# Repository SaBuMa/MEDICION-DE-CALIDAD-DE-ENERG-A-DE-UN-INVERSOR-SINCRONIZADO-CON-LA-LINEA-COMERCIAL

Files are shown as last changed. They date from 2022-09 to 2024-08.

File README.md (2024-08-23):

# Medición de calidad de energía de un inversor sincronizado con la línea comercial
Para este proyecto se realiza el diseño e implementación de un  inversor sincronizado con la línea comercial.

__Aplicaciones:__  
* Fuente de poder ininterrumpida.  
* Red de energía.  
* Paneles solares.

## Como características funcionales de este proyecto se tienen:

* __Inversor__
    * Vo = 9 VRMS  ± 2%
    * Fo = 60 Hz ± 5%
    * Po = 15W
* __Sincronización__
    * Enganche Fo = 60 Hz ± 5% (57 Hz – 63 Hz)
* __Medición de calidad__
    * Medición con módulo de adquisición
    * Acondicionamiento  de entrada de voltaje y corriente.
    * Rango dinámico de 80 dB
    * Variables a medir Vo (RMS), Io (RMS) y THD para estas.

## Equipo electrónico utilizado en este proyecto

<p align="center">
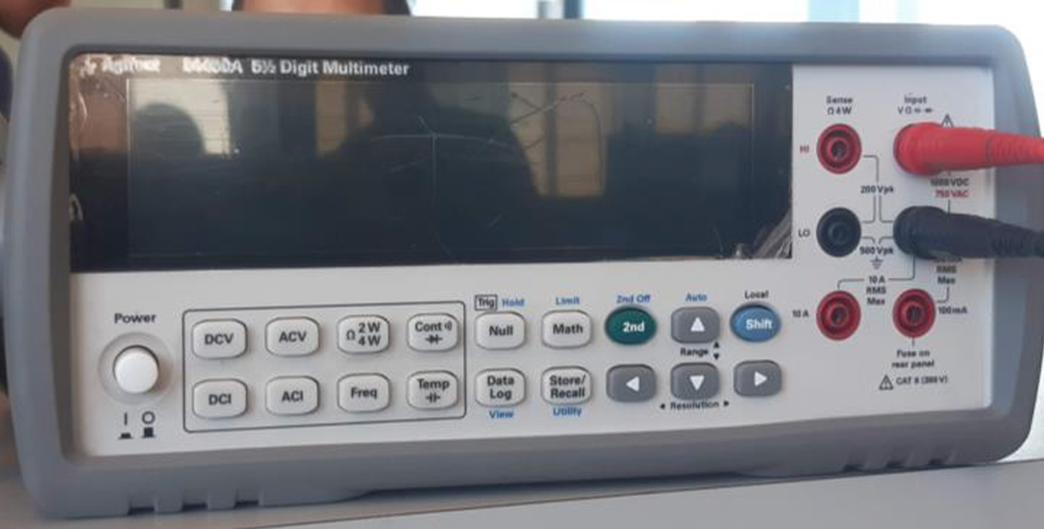
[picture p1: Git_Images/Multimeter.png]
Multimeter
  
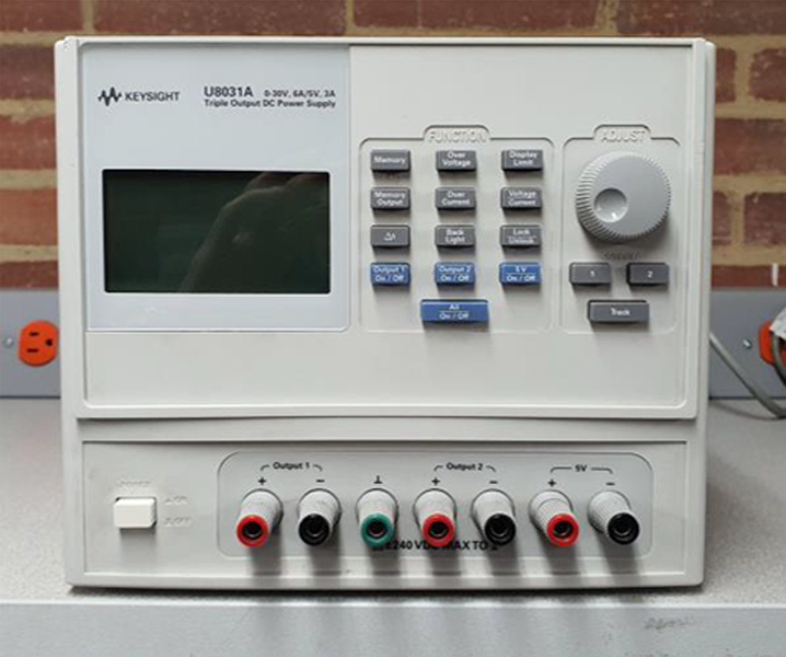
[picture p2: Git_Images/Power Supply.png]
Power Supply

</p>

<p align="center">
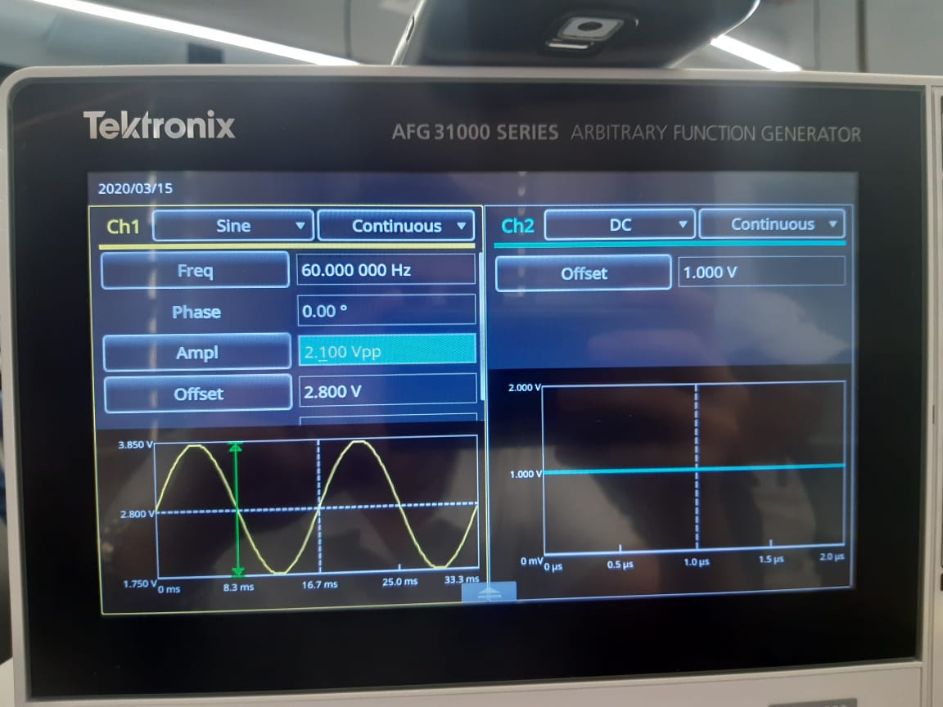
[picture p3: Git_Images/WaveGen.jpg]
WaveGen

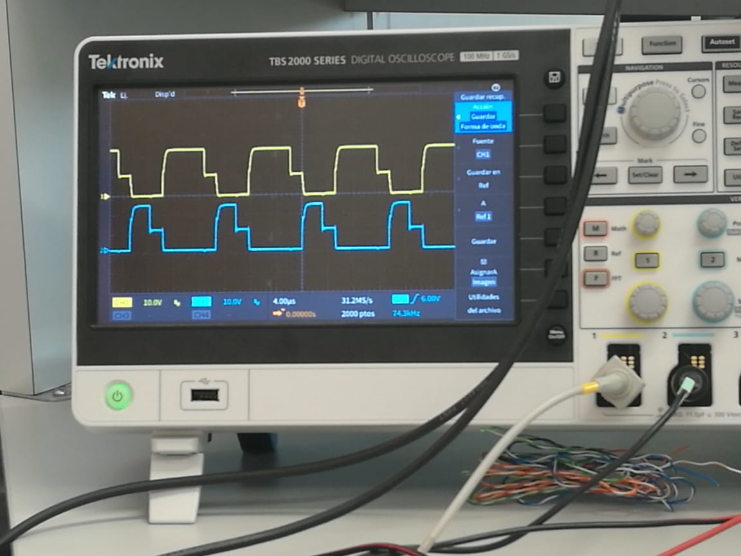
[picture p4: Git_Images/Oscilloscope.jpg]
Oscilloscope

</p>

## Diagrama Bloques proyecto
<p align="center">
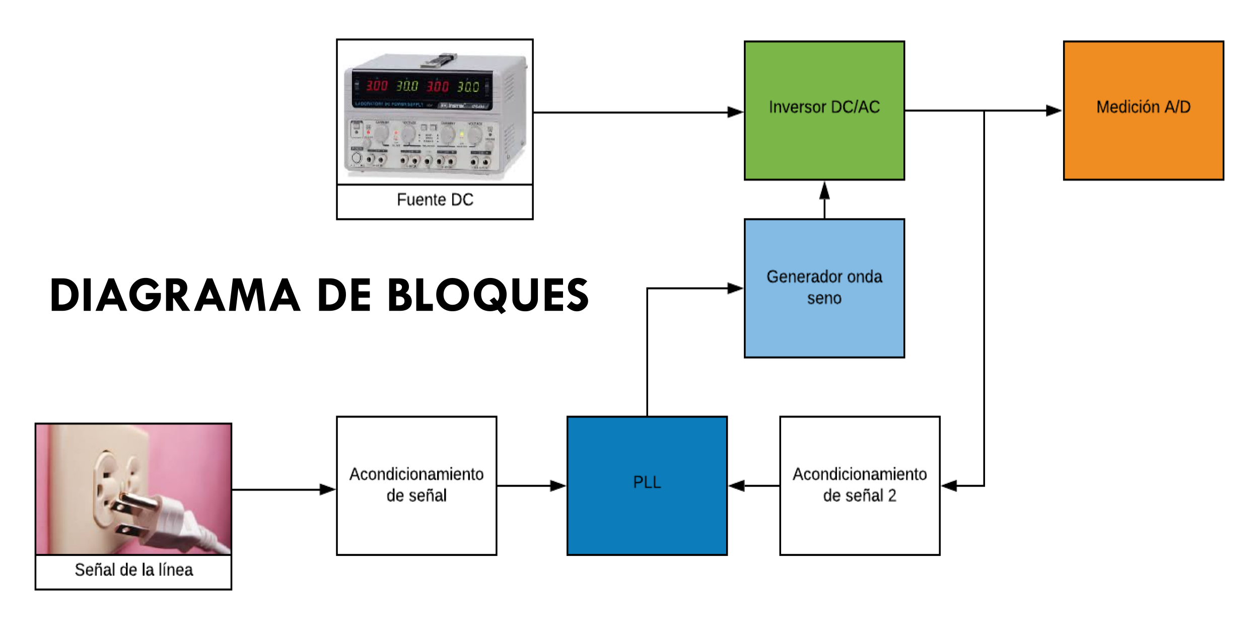
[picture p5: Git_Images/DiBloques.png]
DiBloques
  
</p>

## Acondicionamiento línea comercial  
Reducir el voltaje de 120 VRMS AC de la línea a un voltaje no mayor a 9 VRMS AC.
Proporcionar la señal cuadrada al PLL para que este funcione correctamente.

## Circuito Inversor Esquemático  
<p align="center">
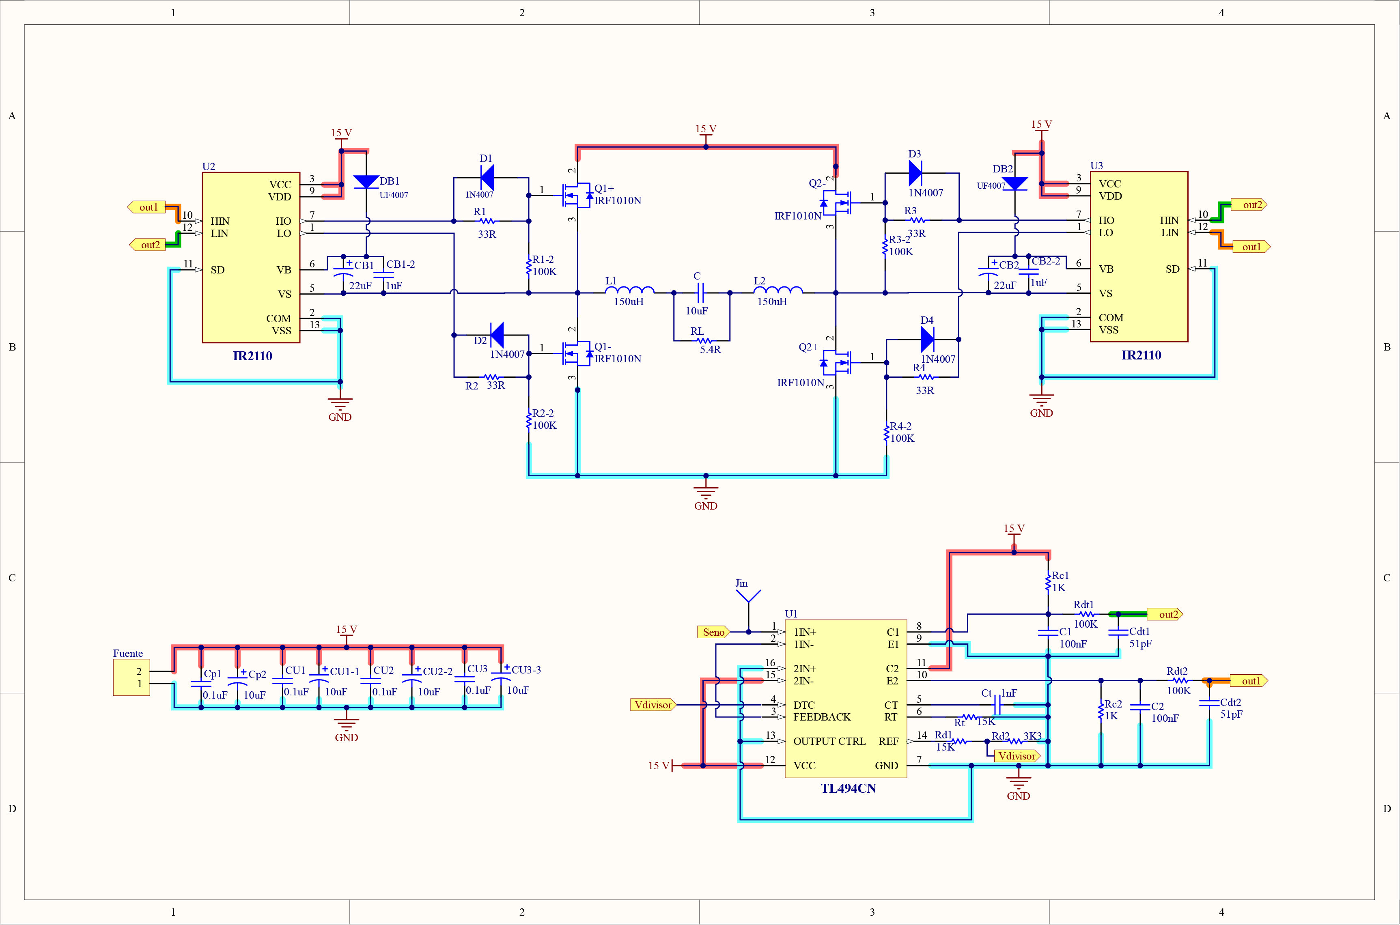
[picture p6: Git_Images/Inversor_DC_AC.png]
Inversor_DC_AC
  
</p>

## Circuito PLL  
Debe sincronizar la salida del inversor con la línea comercial acondicionada.  
Capacidad de enganchar una señal a la línea en un rango de +- 3 Hz.

<p align="center">
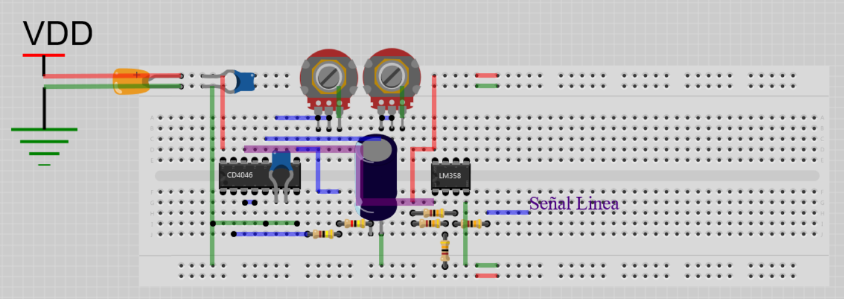
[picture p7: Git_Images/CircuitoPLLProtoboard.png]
CircuitoPLLProtoboard
  
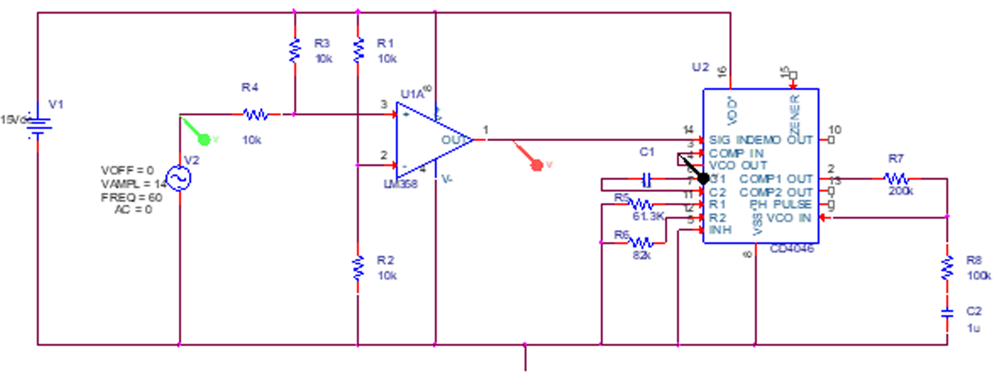
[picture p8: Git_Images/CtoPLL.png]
CtoPLL
  
</p>

## Circuito VCO - Generador onda seno  
<p align="center">
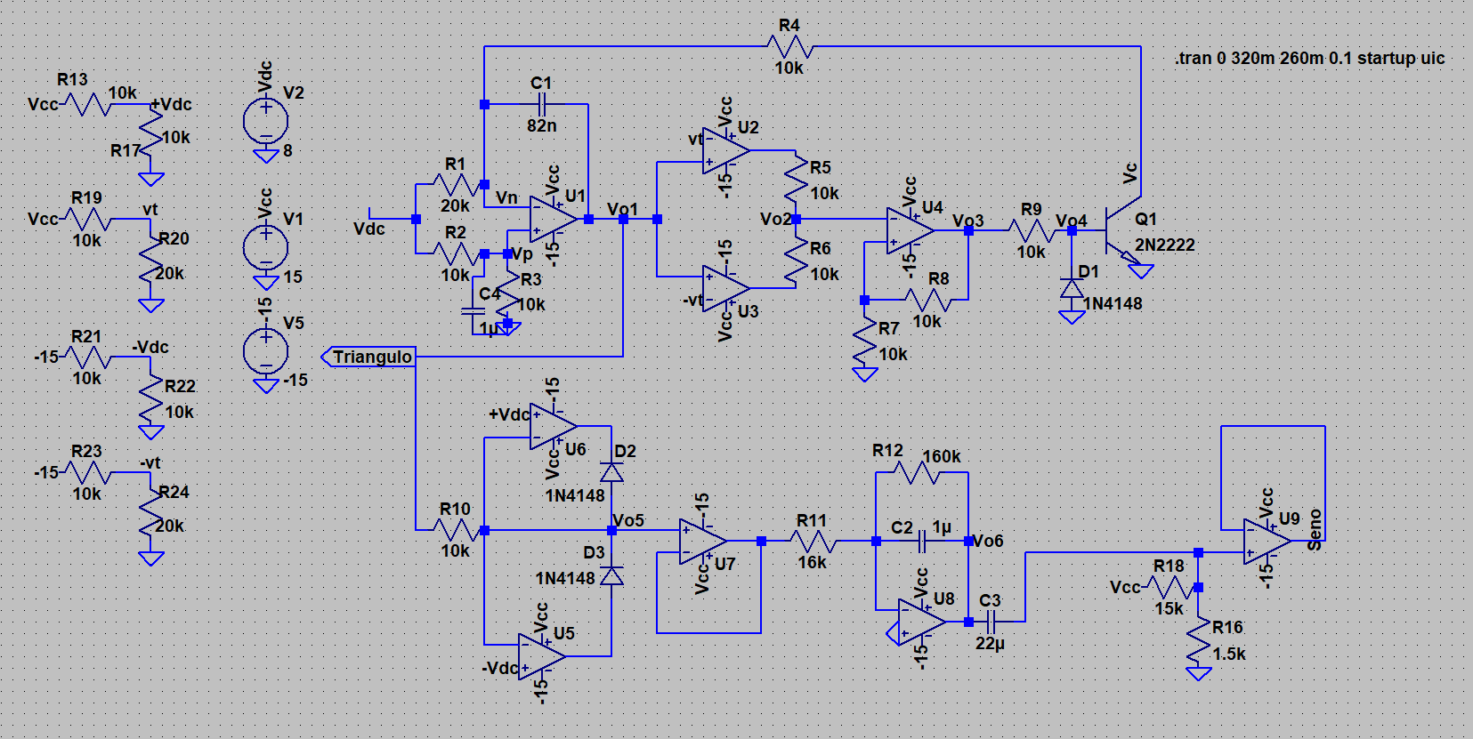
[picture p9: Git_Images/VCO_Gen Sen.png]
VCO_Gen Sen
  
</p>

## PCB del Proyecto  

<p align="center">
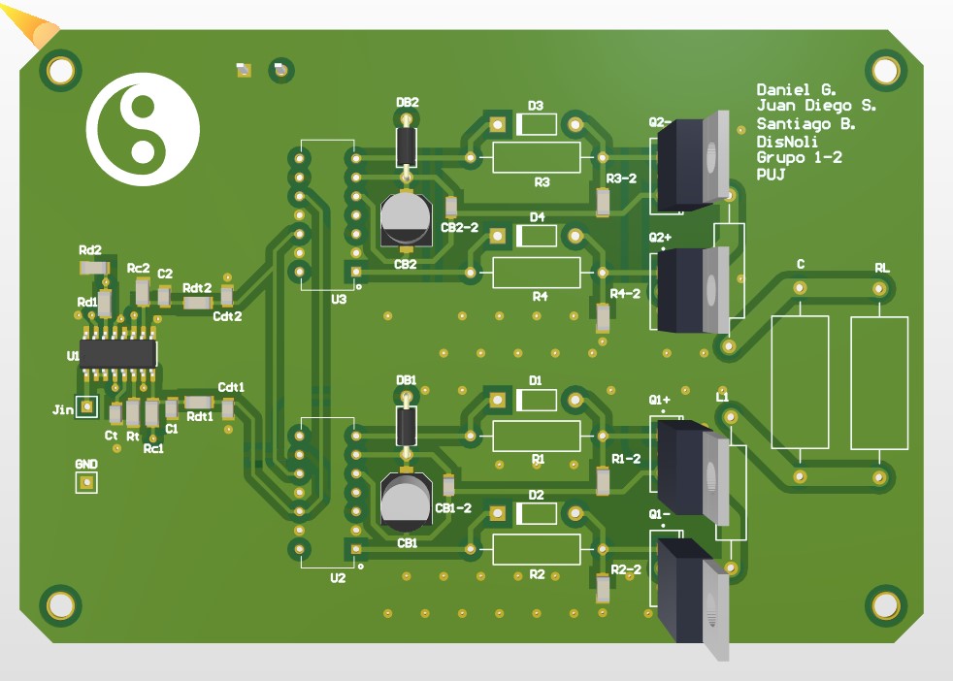
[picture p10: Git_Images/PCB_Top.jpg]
PCB_Top
  
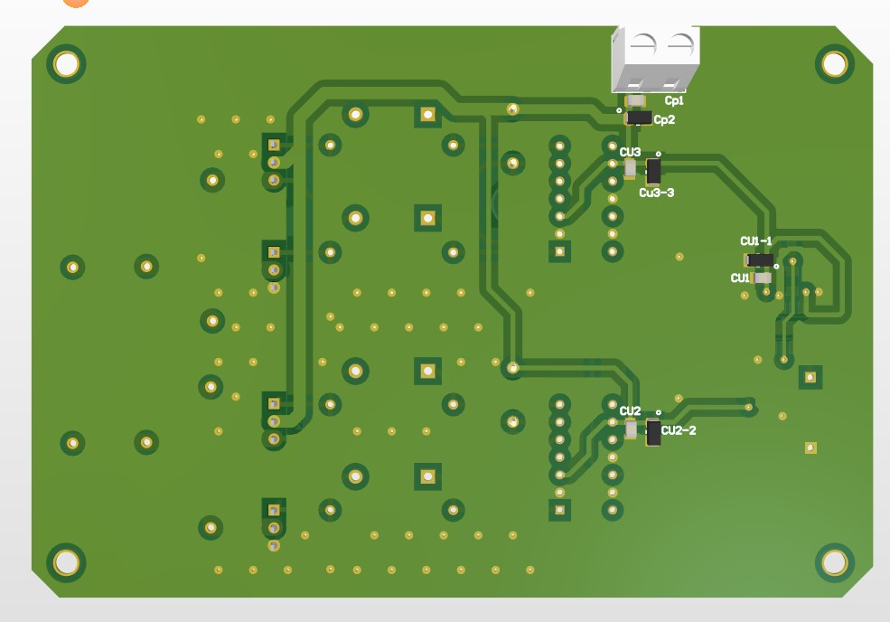
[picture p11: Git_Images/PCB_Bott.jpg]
PCB_Bott
  
</p>

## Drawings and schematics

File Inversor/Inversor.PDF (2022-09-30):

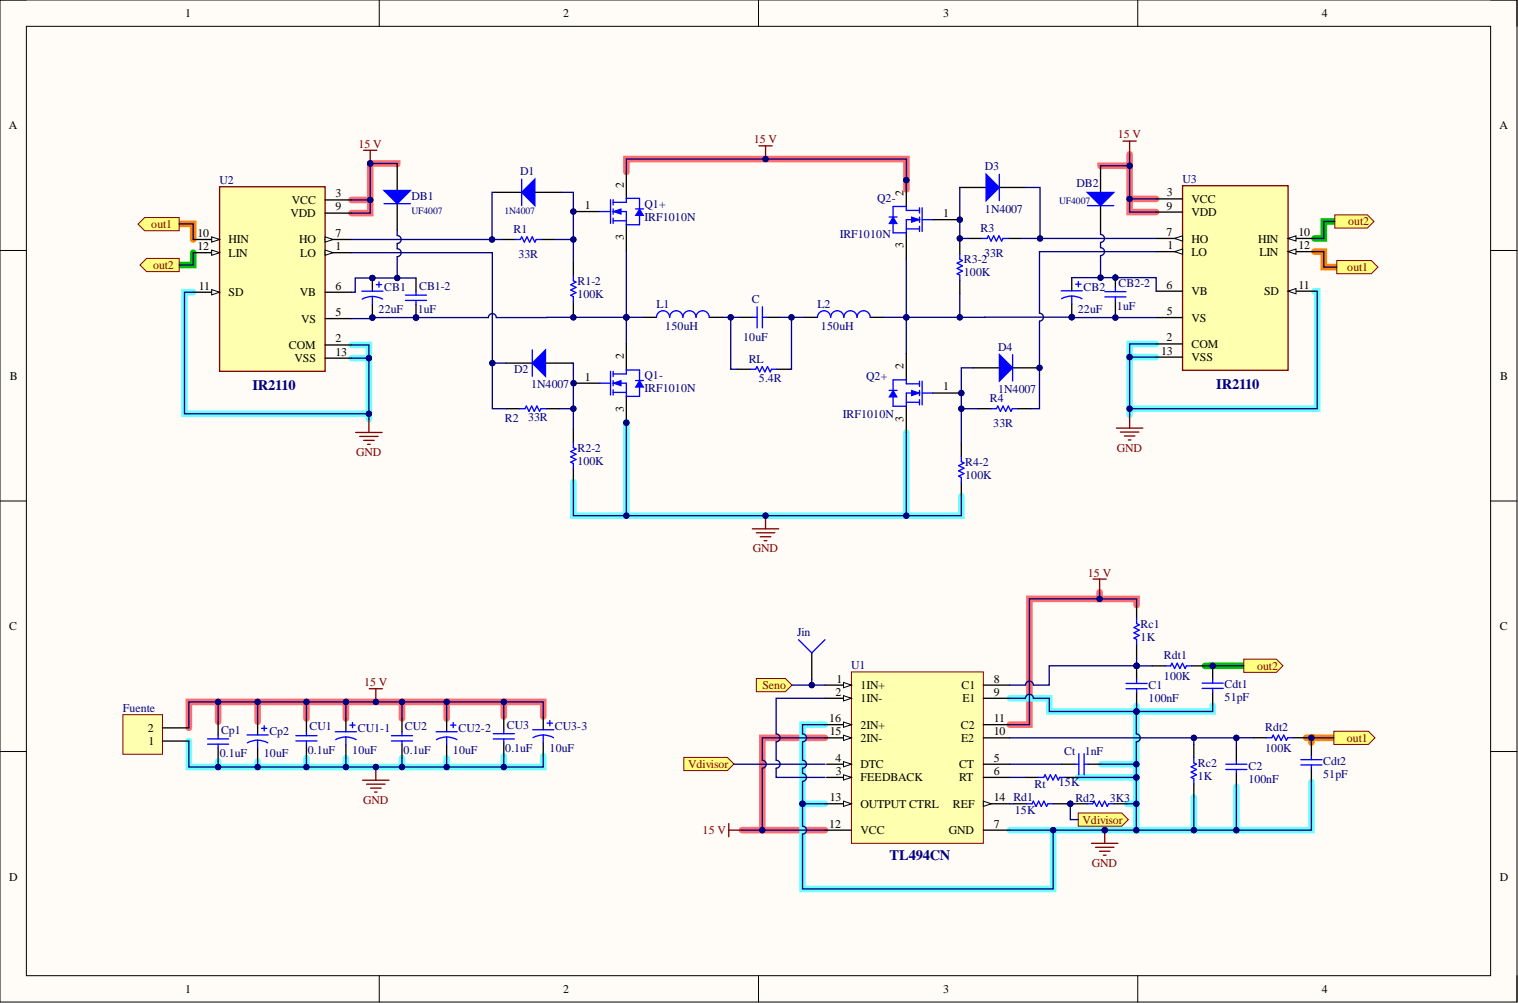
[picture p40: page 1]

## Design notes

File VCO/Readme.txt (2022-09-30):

En esta carpeta se encuentran los calculos y componentes usados en en el circuito de VCO

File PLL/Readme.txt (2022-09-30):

En esta carpeta estan los calculos y componentes para el circuito de PLL

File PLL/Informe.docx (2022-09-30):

DISEÑO DE CIRCUITOS NO LINEALES

INFORME

GRUPO 2

Daniel Esteban González Zuluaga

Juan Diego Sánchez Parra

Santiago Burgos Martínez

18/Febrero/2020

CIRCUITO ESQUEMÁTICO COMPLETO DEFINITIVO

1. Circuito esquemático completo definitivo

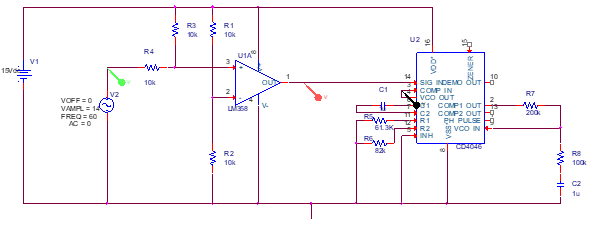
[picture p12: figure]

Figura 1. Esquemático definitivo.

2. Listado de componentes definitivo con número de parte

Componente | Cantidad | Número de parte | Esquemático
CD4046 | 1 | 296-2052-5-ND (https://www.digikey.com/product-detail/en/texas-instruments/CD4046BE/296-2052-5-ND/67295) | U2
LM358 | 1 | 296-1395-5-ND (https://www.digikey.com/product-detail/en/texas-instruments/LM358P/296-1395-5-ND/277042) | U1A
Potenciómetro 100k | 2 | RV4N104C-ND (https://www.digikey.com/product-detail/en/precision-electronics-corporation/RV4NAYSD104A/RV4N104C-ND/222811) | R5,R6
Resistencia 100k | 1 | | R8
Resistencia 200k | 1 | | R7
Resistencia 61.3k | 1 | | R5 (resistencias de precisión para reemplazar los potenciómetros)
Resistencia 82k | 1 | | R6 (resistencias de precisión para reemplazar los potenciómetros)
Resistencia 10k | 4 | | R1,R2,R3,R4
Capacitor 0.1 uF (Poliéster) | 1 | | Polarización
Capacitor 1 uF (Poliéster) | 1 | | C1
Capacitor 10 uF (Tantalio) | 1 | | Polarización
Capacitor 1 uF (Electrolítico) | 1 | | C2

Tabla 1. Listado de componentes.

3. Imágenes de los layers del PCB diseñado (si aplica) especificando dimensiones del mismo

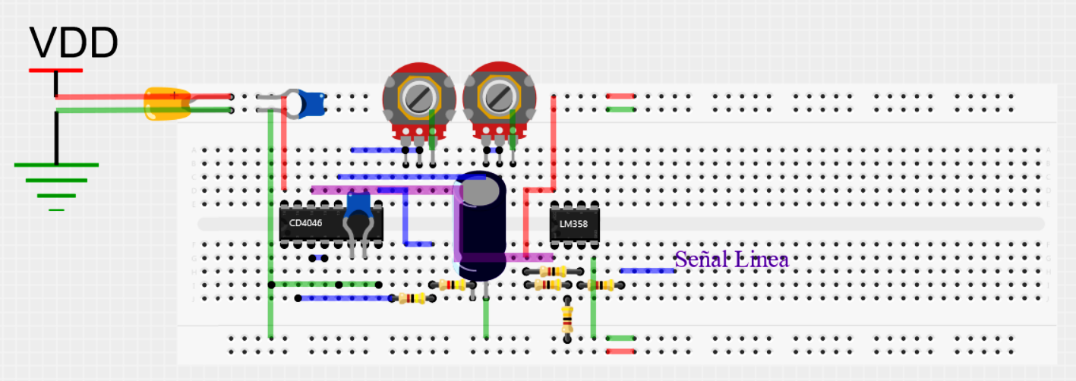
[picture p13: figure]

Figura 2. Implementación en Protoboard del esquemático completo.

PROTOCOLOS DE PRUEBAS EMPLEADOS

1. Variables medidas
- Polarización de los integrados CD4046 y LM358
- Voltaje en el pin 2 (entrada no inversora) del integrado LM358
- Pin 1, salida del integrado LM358.
- Pin 4 (salida del VCO) del integrado CD4046
- Pin 14 (entrada de la señal principal) del integrado CD4046
2. Rango de estas medidas
- Polarización: la polarización es single y va de 0V (GND) a 15V
- El voltaje en el terminal 2 del integrado LM358 debe ser de Vcc/2 = 7.5
3. Equipos e instrumentos utilizados con sus referencias

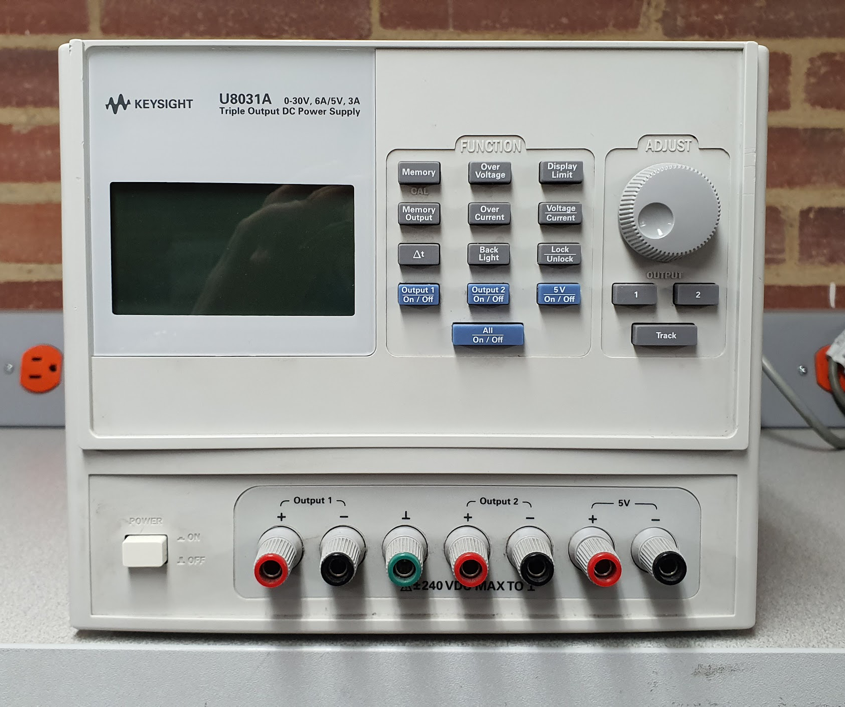
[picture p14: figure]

Figura 3. Fuente de alimentación KEYSIGHT U8031A

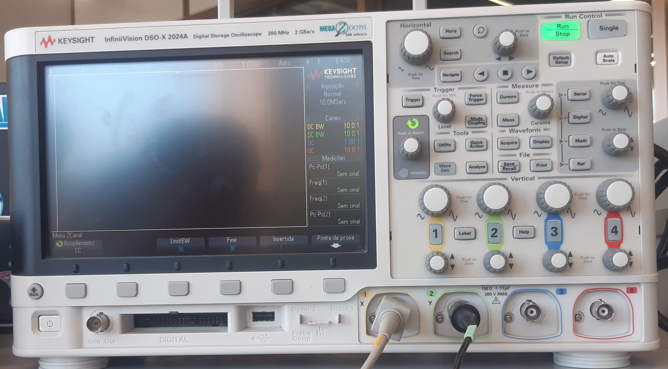
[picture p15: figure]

Figura 4. Osciloscopio KEYSIGHT DSO-X2024A

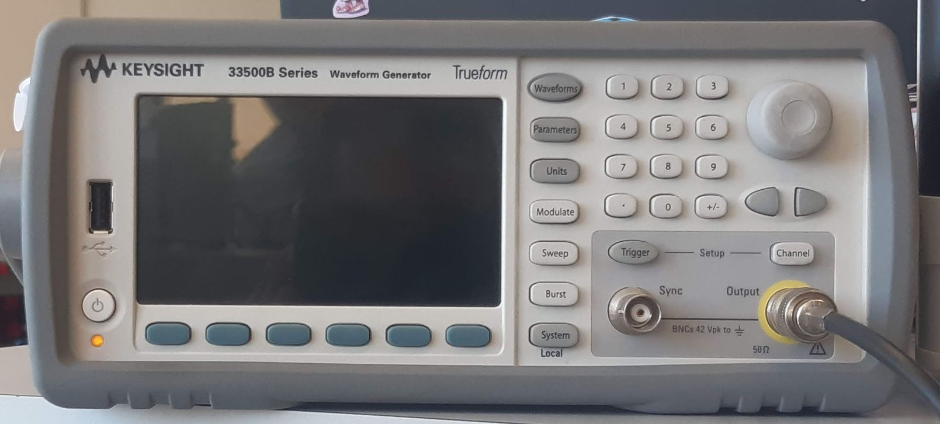
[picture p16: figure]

Figura 5. Generador de funciones KEYSIGHT 33500B

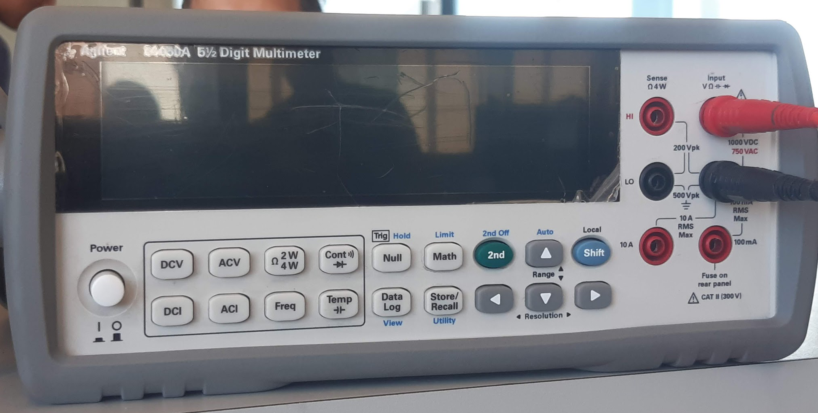
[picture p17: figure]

Figura 6. Multímetro AGILENT 34401A

ANÁLISIS DE LOS RESULTADOS OBTENIDOS

Los resultados obtenidos de la realización de esta práctica fueron: la obtención de un rango de enganche en frecuencia que va desde 32Hz hasta 67 Hz y un desfase de la frecuencia central requerida (60Hz) respecto a la señal de salida del VCO de 132°.

En la figura 7 se puede ver la salida del CD4046 comparado con la señal de la línea comercial, según el diseño de PLL el desfase debe estar entre 0° y 180° (desfase máximo de π), en la gráfica se puede identificar el enganche a una frecuencia de 60 Hz. Para lograr esta comparación se tuvo que acondicionar la señal de la línea para que pudiera ser recibida por el integrado CD4046, esto se logra usando un circuito comparador basado en el integrado LM358. Con el circuito comparador la onda sinusoidal pasa a ser una onda cuadrada como se puede ver en la Figura 8 (línea sin acondicionar) y en la Figura 9 (línea acondicionada).

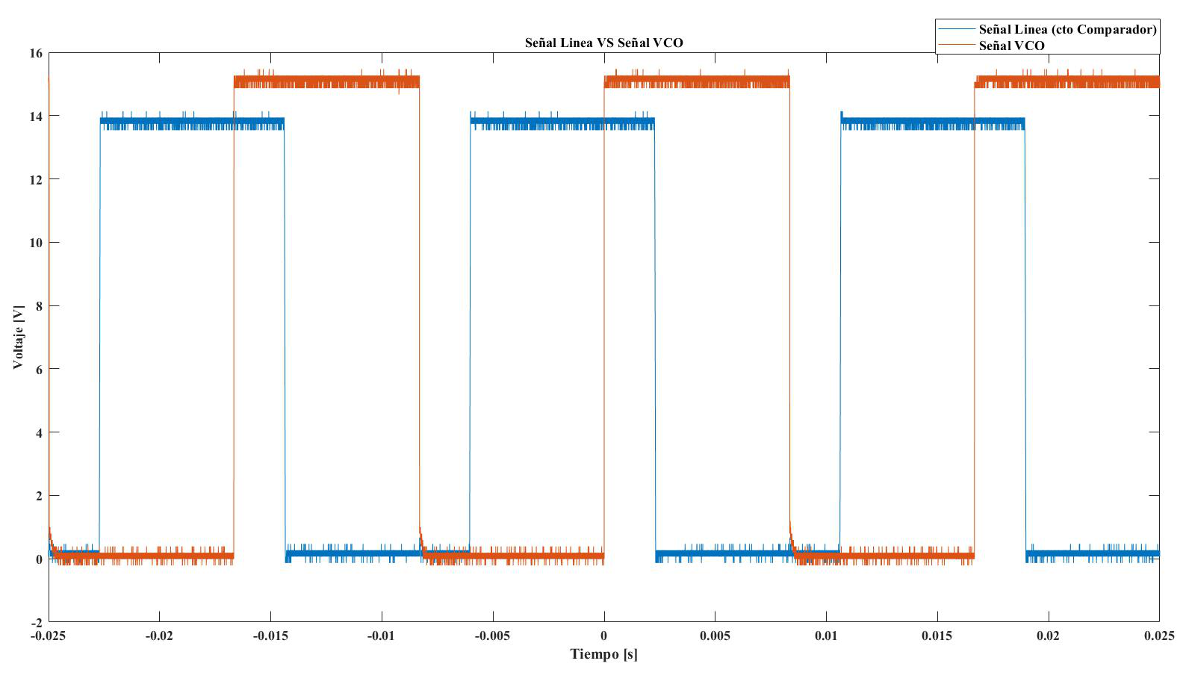
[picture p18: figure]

Figura 7. Señal línea VS salida VCO.

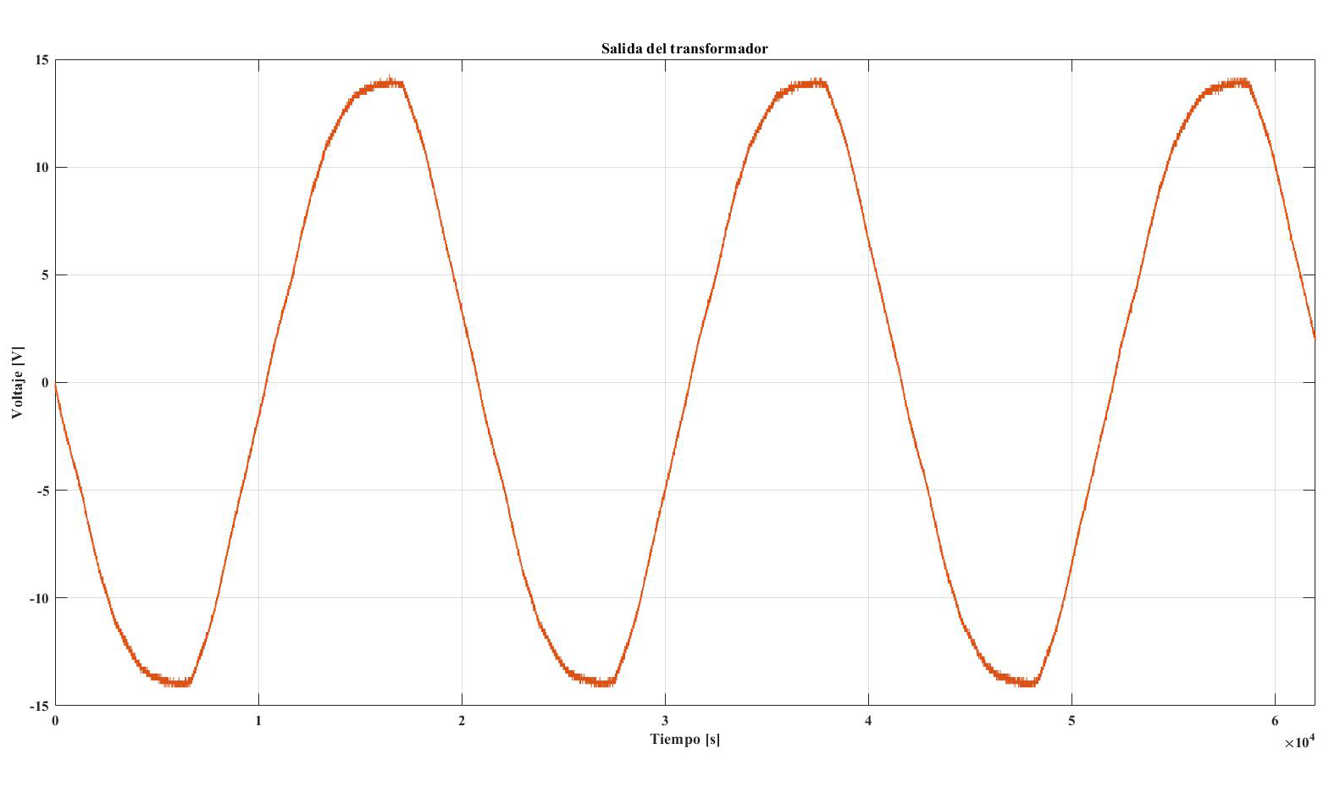
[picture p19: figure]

Figura 8. Salida del transformador.

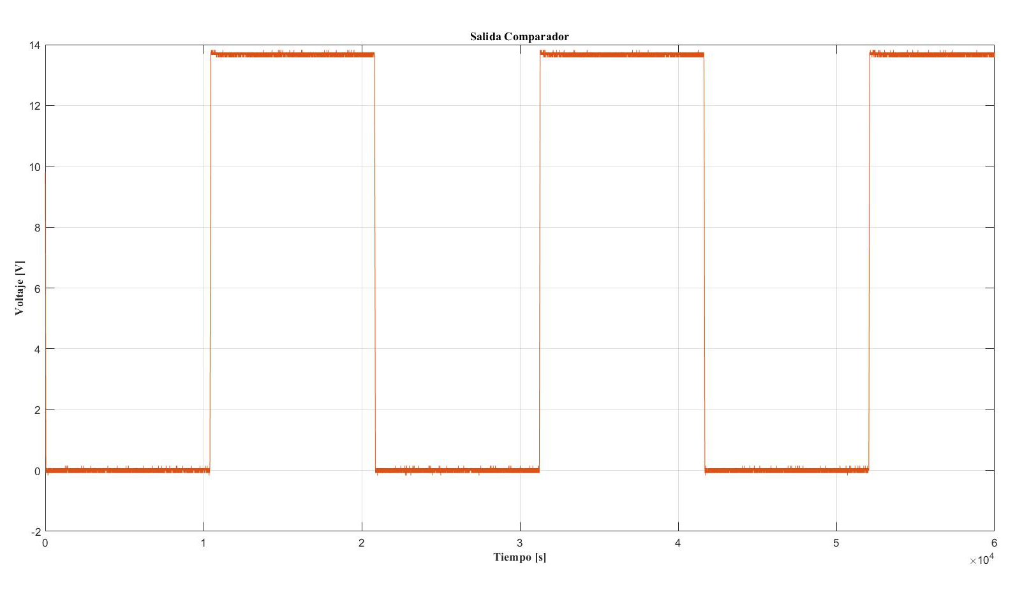
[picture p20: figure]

Figura 9. Salida comparador LM358

Para observar los rangos de enganche del PLL y realizar pruebas de funcionamiento de este, la entrada de la línea acondicionada se sustituye por el generador de funciones (Figura 5) para así de esta manera poder realizar cambios en la frecuencia. Como se mencionó el límite de enganche por debajo de la frecuencia central es de 32 Hz visto en la Figura 10, y el límite por arriba de la frecuencia central es de 67 Hz visto en la Figura 11.

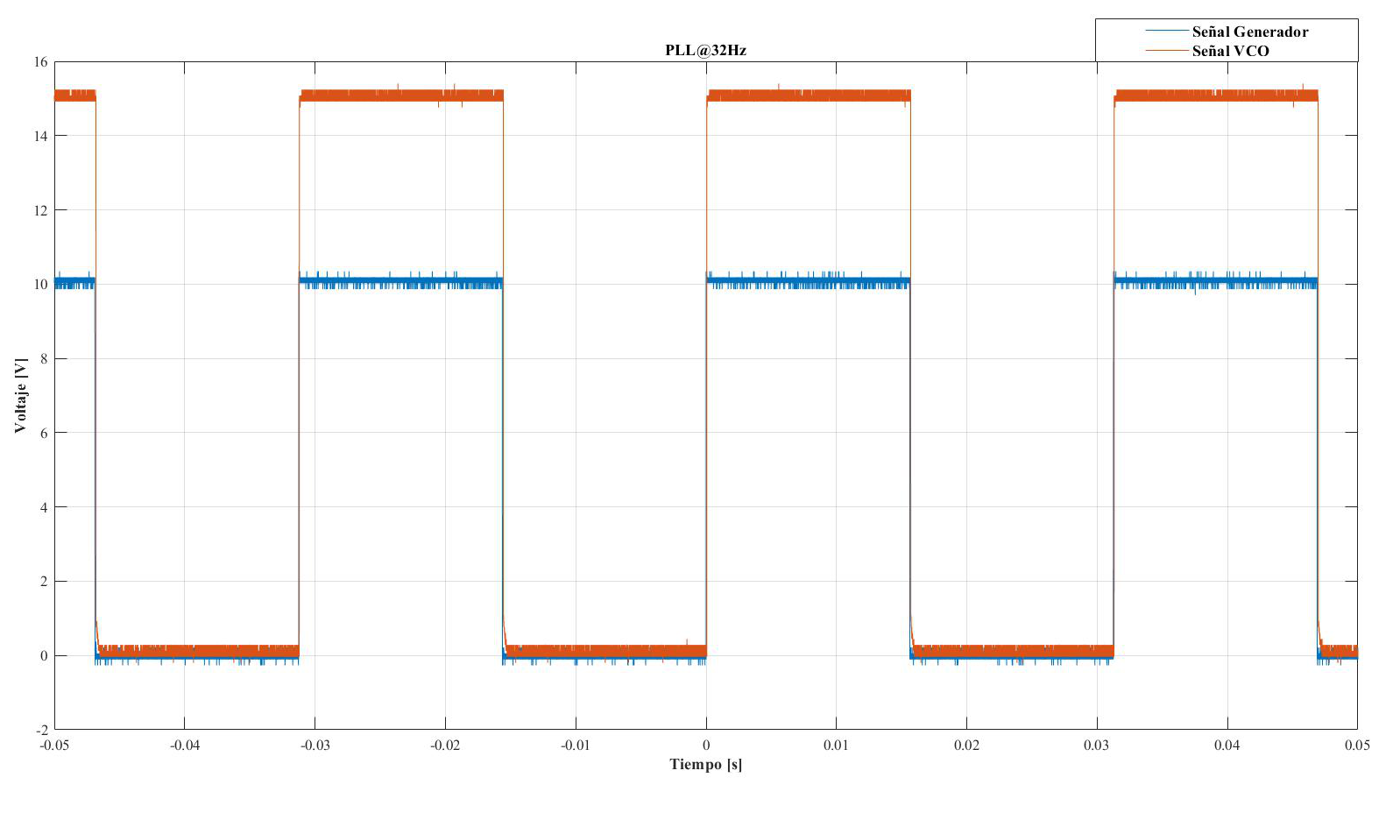
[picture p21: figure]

Figura 10. Enganche a 32 Hz.

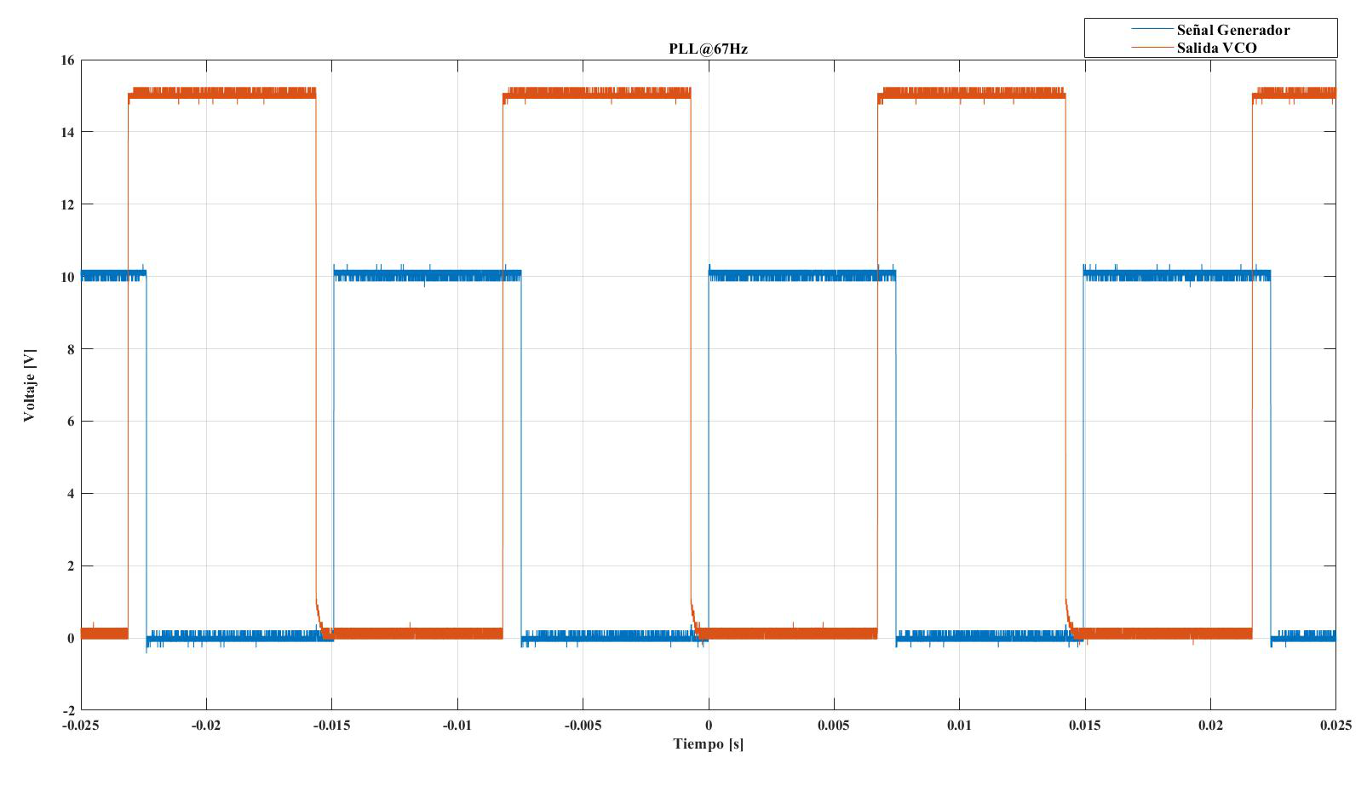
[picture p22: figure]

Figura 11. Enganche a 67 Hz.

1. Cuadro comparativo entre valores teóricos y/o simulados con respecto a los obtenidos con el diseño.

Protocolo de pruebas

Mediciones | Simulación | Experimental | Teórico
Polarización V+ V- | 15 V 0 V | 15.016 V 0 V | 15 V 0 V
Señal VCO Vpp Offset Frecuencia | 15 Vpp 7.5 V 60 Hz | 15.5 Vpp 7.45 V 60 Hz | 15 Vpp 7.5 V 60 Hz
Salida comparador Vp | 13.8 Vp | 14.5 Vp | 15 V
Salida del transformador | 9 VRMS 12.728 Vp 25.456 Vpp | 10 VRMS 14.2 Vp 28.5 Vpp | 9 VRMS 12.728 Vp 25.456 Vpp
PLL@60Hz fase | No Aplica | 136.7° | No Aplica
PLL@32Hz fase | No Aplica | 0.57° | No Aplica
PLL@67Hz fase | No Aplica | 162.32° | No Aplica

Tabla 2. Protocolo de pruebas.

2. Evaluación de los resultados

La comparación de los resultados obtenidos con los cálculos teóricos permiten determinar la calidad y el correcto funcionamiento del diseño realizado, ahora, en algunos resultados experimentales se tienen ciertas diferencias respecto a los teóricos: como lo son los rangos de enganche y voltajes de salida que no son exactos, ya que en los cálculos teóricos se tenía un rango de enganche Δf=±3Hz y se obtuvo Δf=22Hz por debajo, y Δf=7Hz por encima, teniendo en cuenta la fo=60Hz . Sin embargo, el resultado en general del PLL es el esperado con los cálculos y la simulación, obteniendo en la práctica valores de desfase cercanos y acuerdo a los teóricos.

PROBLEMAS PRESENTADOS DURANTE EL DISEÑO

1. Descripción de los problemas encontrados durante el diseño
- La calibración/ajuste de la frecuencia central del VCO para los rangos de enganche, la cual depende de los potenciómetros, se complicó debido a la falta de resistencias de precisión.
- Pasar de una onda seno a una onda cuadrada para poder entrar al integrado CD4046 (acondicionamiento), esto debido a que la comparación de señales que realiza el PLL es entre señales cuadradas.
- Reducción del voltaje nominal de la línea por medio de un transformador reductor, debido a que los integrados estaban polarizados a un voltaje de 15V y en sus terminales no pueden recibir el voltaje de la línea sin una previa modificación.
2. Descripción de soluciones implementadas

Se pudo observar que el enganche dependía considerablemente del valor de las resistencias R5 y R6, ya que en un principio no se lograba crear un enganche usando resistencias no variables, al ser reemplazarlas por potenciómetros se consiguió el enganche. Ahora, para pasar la onda seno a cuadrada se realizó la investigación pertinente acerca de los comparadores para conseguir una señal apta (a partir de la señal de la línea) para entrar al PLL.

Por último, el uso de un transformador reductor, el cual entrega en su salida una onda seno de 10 VRMS, con la cual ya es posible trabajar y ser manejada por los integrados de los circuitos del proyecto.

3. Cambios realizados durante el diseño

En el diseño (cálculos teóricos y simulación) se quería un rango de enganche que estuviera entre 57 Hz y 63 Hz, en la práctica se observa que el rango obtenido se amplía considerablemente y se llega a tener un rango de 33 Hz hasta 67 Hz, como se puede observar en las Figuras 10 y 11, esta consideración no afecta el proyecto ya que el objetivo es que haya enganche con la línea.

4. Posibles alternativas para mejorar el diseño implementado

Para poder mejorar el diseño se quiere implementar el circuito en PCB, pero esta opción será aplazada hasta la presentación del proyecto final, debido a que se traen algunos componentes desde Estados Unidos. Por último, para garantizar el mismo enganche que con la protoboard se utilizaran Trimmers.

CONCLUSIONES

Se presentaron algunos inconvenientes en el desarrollo del PLL específicamente en cuadrar la frecuencia de oscilación del VCO, teniendo en cuenta las dos resistencias que la modificaban. Sin embargo, el resultado en general del PLL es el esperado con los rangos de enganche que cumplen los requerimientos y objetivos propuestos. Otro aspecto en el que se pudo avanzar fue el uso del transformador y el comparador con los cuales se acondicionó la señal de la línea.

BIBLIOGRAFÍA

[1] Bhag S. Guru y Hüseyin R. Hiziroglu, Maquinas electricas y transformadores, Retrieved from

https://www.academia.edu/27018835/Maquinas_Electricas_y_transformadores.Bhag_S._Guru.pdf

[2] A. A. Khan, H. Cha and H. F. Ahmed, "High efficiency buck and boost type AC-AC converters," 2015 17th European Conference on Power Electronics and Applications (EPE'15 ECCE-Europe), Geneva, 2015, pp. 1-10.

doi: 10.1109/EPE.2015.7309136 http://ieeexplore.ieee.org.ezproxy.javeriana.edu.co:2048/stamp/stamp.jsp?tp=&arnumber=7309136&isnumber=7309048

# [3] Optoacoplador, que és y cómo funciona https://hetpro-store.com/TUTORIALES/optoacoplador/ , consultado el 03/02/2020

[4] CD4046B Phase-Locked Loop: A Versatile Building Block for Micropower Digital and Analog Applications, http://www.ti.com/lit/an/scha002a/scha002a.pdf , consultado el 03/02/2020

[5]El Disparador Schmitt, tomado de http://hyperphysics.phy-astr.gsu.edu/hbasees/Electronic/schmitt.html , Consultado 21/10/2013.

[6] Fairchild (2010). Dual Operational Amplifier Lm358. Retrieved from.https://www.sigmaelectronica.net/manuals/LM358A.pdf

[7] Datasheet integrado CD4046 - (https://www.sigmaelectronica.net/manuals/CD4046.pdf)https://www.sigmaelectronica.net/manuals/CD4046.pdf - Consultado 21/10/2013.

[8] Best, R. E. (1993). Phase-locked loops. theory, design and applications. McGraw-Hill. Retrieved from https://search-ebscohost-com.ezproxy.javeriana.edu.co/login.aspx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

[9] Transformador MAGOM M-507 https://magomelectronica.com/asc/producto/transformador-m-507/

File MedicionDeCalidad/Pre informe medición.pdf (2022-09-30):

DISEÑO DE CIRCUITOS NO LINEALES

PREINFORME ENTREGA 4: MEDICIÓN DE CALIDAD

GRUPO 2

Daniel Esteban González Zuluaga

Juan Diego Sánchez Parra

Santiago Burgos Martínez

14/Abril/2020

DEFINICIÓN DEL PROBLEMA

1. Descripción de la temática a tratar

En esta parte se presentará la etapa de medición del funcionamiento del proyecto, midiendo y analizando la calidad de energía en salida del Inversor, esto mediante un módulo de adquisición de señales, que permita medir; voltaje y corriente RMS, y THD de voltaje y corriente con variaciones de carga.

Para realizar unas buenas mediciones en el módulo de adquisición se debe lograr que, a este, le entren las señales lo mejor posible, eliminando lo que no se quiere medir y haciendo que esta señal se adapte a los requerimientos del módulo. Con esto se quiere decir que es necesario un acondicionamiento de la señal de salida del inversor, entre estos un reductor de voltaje y un filtro que se detallarán más adelante.

2. Alcance del diseño

La etapa de medición de calidad y funcionamiento del proyecto lograr recopilar y realizar un análisis de las variables de voltaje y corriente de salida del Inversor. Para llevar a cabo esta tarea se plantea el uso de circuitos de acondicionamiento de señal como la implementación de un circuito de filtro pasa bajas. Las señales provenientes de los dos tipos de circuitos mencionados previamente serán ingresadas en un módulo de adquisición de National instruments el cual permitirá establecer una interfaz para el procesamiento de la información por medio de un computador.

3. Análisis de fenómenos físicos: mecánicos, eléctricos, etc., que permitan plantear la solución en términos de ingeniería.

Filtro Anti Aliasing: Es un tipo de filtro pasa bajos analógico, el cual está presente usualmente antes de realizar una conversión análoga/digital. Este tipo de filtro sirve para hacer una limpieza de la señal antes de hacer la conversión, para esto se tiene en cuenta la señal (Frecuencia máxima) que se quiere dejar pasar, donde idealmente después de la frecuencia de corte ya no habrá señal alguna. El valor de esta frecuencia se escoge en base a dos razones: La primera, es necesario tener en cuenta cuántos armónicos van a pasar. Para este caso se tiene como criterio de diseño que la señal medida se asemeje lo más posible a la señal de salida del inversor (idealmente entre mayor cantidad de armónicos mejor resolución en las medidas), para este diseño se escogió pasar 9 armónicos. La segunda, es por el teorema de muestreo de Nyquist, el teorema dice que la frecuencia de corte debe ser por lo menos 2 veces menor a la frecuencia de muestreo. Para este caso, como se mencionó previamente, van a pasar 9 armónicos es decir hasta la frecuencia de corte será de 600 Hz y el doble de esta frecuencia que es igual a 1200 Hz, debe ser la mínima frecuencia de muestreo que se debe tener, por criterio se escoge 5000Hz.

PROPUESTA DE SOLUCIÓN

1. Descripción general de la solución propuesta

La solución está compuesta por un circuito el cual acondiciona el voltaje de salida del Inversor para luego pasar por un filtro pasa bajas de orden superior a 5 el cual permitirá obtener una señal con la información necesaria para ser analizada posteriormente. Para la adquisición de los datos correspondientes a la corriente de salida del inversor se plantea el uso de una resistencia en serie a la resistencia de carga del circuito la cual cumple la función de una resistencia “SHUNT”, esta será una resistencia con un alto valor de precisión para garantizar que los datos obtenidos por medio de esta tengan la mejor resolución posible.

2. Análisis y justificación de la solución

Para llevar a cabo una medición y toma de datos adecuada, se hace necesario acondicionar las señales que se van a medir teniendo en cuenta los parámetros y características del instrumento que va a realizar la toma de datos, es decir, el Módulo de adquisición. Ahora, teniendo en cuenta los límites y características de las señales que el módulo puede leer y recibir se realiza en concordancia el diseño de circuitos de acondicionamiento o de medición para ser leídos e ingresado finalmente al módulo.
En esencia, los circuitos que se implementaran y diseñarán para este parte del proyecto son para garantizar que sea posible leerlas por medio del módulo de adquisición.

Resistencia “SHUNT”: Esta resistencia tiene la finalidad de medir y leer el voltaje diferencial en la resistencia que se escoja. Posteriormente usando el programa del módulo de adquisición en el computador se puedan realizar los cálculos necesario para obtener el valor de la corriente que hay en la salida del Inversor, esto haciendo uso de la ley de ohm, ya se tiene el valor de la resistencia la cual se escoge previamente y leyendo el valor del voltaje en el módulo de adquisición se puede encontrar el valor de la corriente. Como se ha explicado anteriormente los bloques de acondicionamiento y filtro de corriente son los mismos que para el voltaje.

3. Descripción de posibles alternativas

Se planteó realizar la medición implementando de manera análoga un circuito DAC. Sin embargo, esta propuesta fue superada/descartada desde el principio debido a las especificaciones en las que se determinaba el uso del módulo de adquisición.

4. Especificaciones generales a cumplir
- Acondicionar la señal de salida del inversor para ser medida por el Módulo de adquisición.
- Medir el voltaje y corriente RMS de salida del inversor.
- Obtener la información de la distorsión total armónica “THD” tanto del voltaje como de la corriente de la salida del Inversor.

BLOQUES FUNCIONALES

1. Diagrama en bloques de la solución propuesta

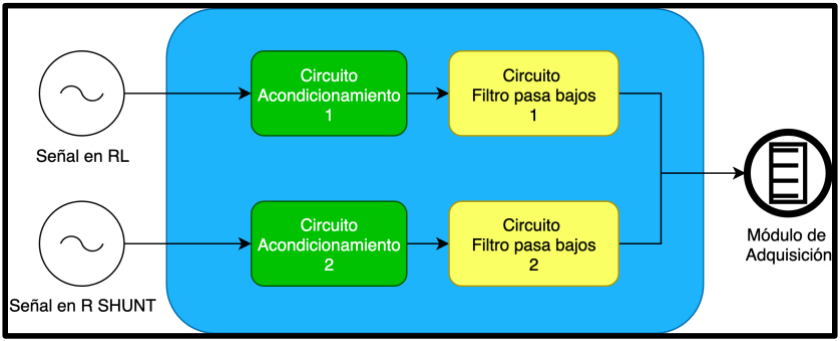
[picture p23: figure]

Figura 1. Diagrama en bloques etapa medición.

Se tiene en cuenta que la entrada para el circuito de acondicionamiento y resistencia SHUNT es diferente, ya que al circuito de acondicionamiento le entra la onda seno, medida sobre las dos patas del capacitor/resistencia de carga. Por el contrario, el circuito de resistencia shunt medirá el voltaje de un terminal del capacitor a un terminal de la resistencia de carga, para después poder usar otro acondicionamiento y poder medir la corriente.

2. Justificación o análisis de cada uno de los bloques funcionales de la propuesta

Teniendo en cuenta la descripción de la solución propuesta, se tienen los siguientes circuitos:

Circuito de acondicionamiento 1 y 2: este circuito cumple la función de referenciar a una tierra común la señal seno de salida del Inversor, esto es necesario y de vital importancia debido a que, en el momento de realizar la toma de datos por medio del Módulo de adquisición, la señal debe tener la misma referencia que el módulo es decir referenciada a tierra, ya que por características internas del dispositivo este no permite el ingreso de señales flotantes.

Circuito filtro Anti-aliasing (pasa bajas) 1 Y 2: este circuito como su nombre lo dice permitirá el paso de las frecuencias inferiores su frecuencia de corte. La implementación de este circuito se realiza con la intención de obtener la cantidad de información necesaria para el análisis que se quiere realizar. Este circuito se ubica como etapa siguiente al circuito de acondicionamiento,

3. Especificaciones entrada-salida de cada bloque
Teniendo en cuenta la descripción de la solución propuesta, se tienen los siguientes circuitos:

Circuito de acondicionamiento 1 y 2:
Entrada: Voltaje sin referencia, proveniente del Inversor
Salida: Voltaje de la salida del inversor referenciado a una tierra común.

Circuito filtro Anti-aliasing (Pasa bajas):
Entrada: Tiene como entrada la salida del bloque de acondicionamiento
Salida: Señal seno con sus componentes en frecuencia, los cuales están determinados por la frecuencia de corte del filtro.
4. Modelo funcional de cada bloque Circuito de acondicionamiento 1 y 2:

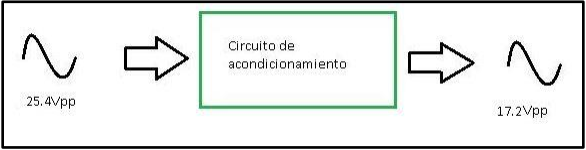
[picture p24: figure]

Figura 2. Modelo funcional acondicionamiento 1

Figura 3. Modelo funcional acondicionamiento 2

Circuito filtro Antialiasing (pasa bajas) 1 y 2:

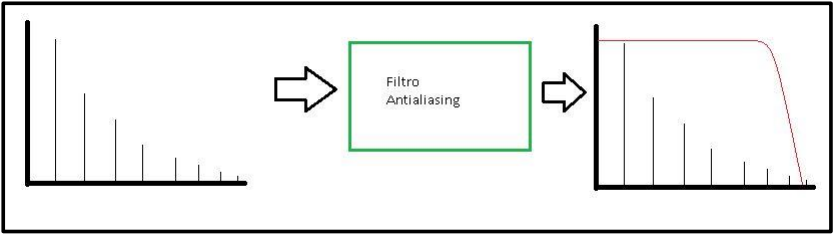
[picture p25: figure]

Figura 4. Modelo funcional filtro antialiasing.

5. Dimensionamiento de componentes (cálculos teóricos con comentarios explicativos y criterios de selección de componentes)

Circuito de acondicionamiento:
Teniendo en cuenta [2], la ecuación característica que representa la variable de salida está dada por:
V−
R5

=

−Vo1
R3

Escogemos R5 y R3de valor de 1k.

V− = −Vo1

−V−
R4

+

V+
R2

=

−Vout
R1

Escogemos R2 y R4de valor de 1k.

−V− + V+
R2

=

−Vout
R1

Para escoger la amplitud final que queremos meterle al DAQ escogemos R1 como 680, gracias a esta última ecuación, Vsource = −V− + V+:.

Vout = −

R1
R2

∗ (VSource)

partiendo de la fórmula anterior se escogieron los siguientes valores de resistencia para el circuito acondicionamiento 1

R1 = 680 Ω
R2 = 1 KΩ
R3 = 1 KΩ
R4 = 1 KΩ
R5 = 1 KΩ

Ahora se necesita agregar otro circuito de acondicionamiento para la medición de corriente ya que esta también se encuentra en modo diferencial. Como se puede observar es el mismo problema que se tiene con la medición del voltaje por lo tanto se usa el mismo circuito para poder referenciar la señal a tierra, con la diferencia que el valor de las resistencias del circuito deben cambiar para que la proporción de Voltaje que se está obteniendo de la resistencia SHUNT sea cercana al límite de medición del DAQ. Para poder comenzar con este cálculo suponemos una resistencia SHUNT muy pequeña para que no altere la resistencia de carga, en este caso se escoge de 100 mΩ. Por lo tanto, el voltaje diferencial que se espera en la resistencia SHUNT es de:

V = I ∗ R
V = 2.36A ∗ 100m
V = 0.236V

Se necesita para sacar la máxima excursión de la señal que este voltaje se acerque a 10 Vpp por los límites del DAQ, con ayuda de la ecuación sacada para medir el voltaje diferencial obtenemos.

Vout = −

R1
R2

∗ (VSource)

10V ≈ −

R1
R2

∗ (0.236V)

Para que esta condición se cumpla se escoge R1 = 47kΩ y R2 = 1.2kΩ.

Vout = −9.24Vpp

Circuito Anti-aliasing:
Para el diseño del filtro pasa bajas se tuvo en cuenta las siguientes características de Arquitectura de filtros y Tipos de filtros [3] :

Tabla 1. Tipos de arquitectura de filtros juntos con sus ventajas y desventajas.(3)

Tabla 2. Tipos de filtro junto con sus ventajas desventajas.

Teniendo en cuenta las tablas previamente mostradas, se optó por una arquitectura Sallen Key, y por un filtro de tipo Bessel. Ahora, con estas dos características escogidas, debido a que el filtro a implementar debe ser mayor a orden 3, por complejidad de las ecuaciones se optó por usar la herramienta “Filter Pro” de Texas Instruments, en la cual se pueden ingresar los parámetros seleccionados además de escoger la atenuación a la que el filtro va a caer, la cual será de -100 dB/dec. Los resultados obtenidos de la aplicación “Filter Pro” se encuentran en Anexo 1.

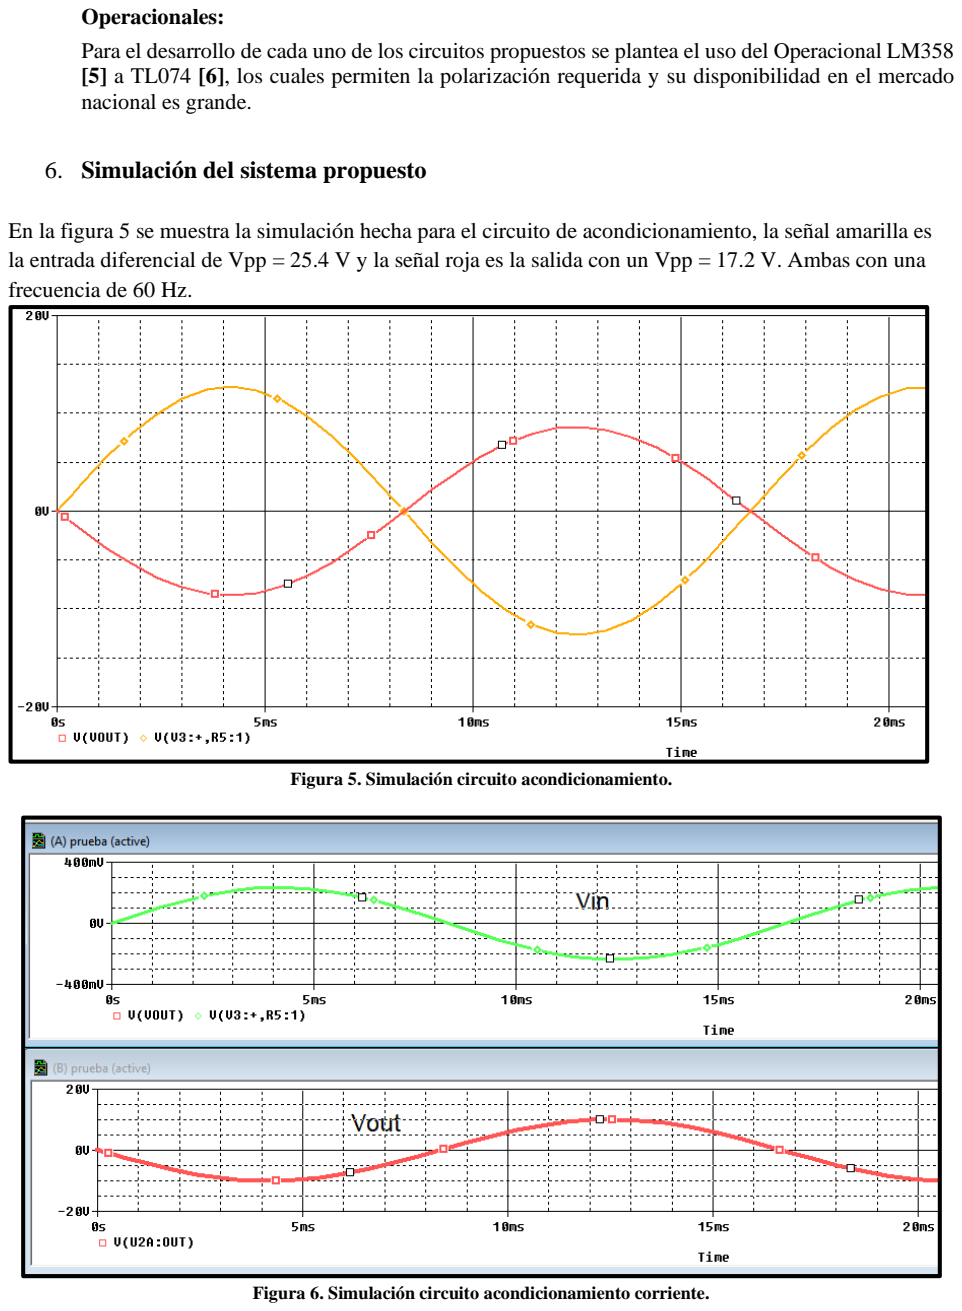
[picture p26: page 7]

Operacionales:
Para el desarrollo de cada uno de los circuitos propuestos se plantea el uso del Operacional LM358
[5] a TL074 [6], los cuales permiten la polarización requerida y su disponibilidad en el mercado nacional es grande.
6. Simulación del sistema propuesto

En la figura 5 se muestra la simulación hecha para el circuito de acondicionamiento, la señal amarilla es la entrada diferencial de Vpp = 25.4 V y la señal roja es la salida con un Vpp = 17.2 V. Ambas con una frecuencia de 60 Hz.

Figura 5. Simulación circuito acondicionamiento.

Figura 6. Simulación circuito acondicionamiento corriente.

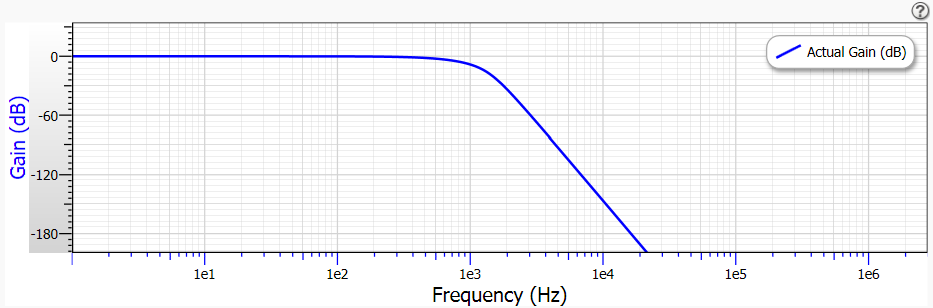
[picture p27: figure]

Figura 7. Salida bode del filtro en Filter pro.

7. Análisis de resultados de simulación, datos, gráficas, tablas, etc.

Cómo se pudo observar en la simulación (Figura 5) se va a disminuir la amplitud de la señal, además de referenciarla a una tierra común para que pueda entrar al DAQ sin dañarlo o tener resultados imprevistos. Teniendo en cuenta [1], la máxima amplitud que permite el DAQ 20 Vpp por esta razón se decidió disminuir la amplitud de la señal de 25.4 Vpp la amplitud a 17.2 Vpp, usando resistencias comerciales para el circuito. Después se observa el filtro antialiasing (Figura 6) que tiene una frecuencia de corte de 600Hz como era previsto, también se tuvo en cuenta que todos los componentes utilizados en este filtro fueran comerciales.

8. Consideraciones especiales o posibles problemas para tener en cuenta durante el montaje y pruebas

Para este diseño se debe tener en cuenta las interconexiones de los componentes en especial la de conexiones que llevan señal para evitar ruido que afecte el desempeño y las medidas del circuito. Además, se tiene presente las consideraciones, especificaciones y límites que presenta en el módulo de adquisición a la hora de medir de corriente y voltaje.

BIBLIOGRAFÍA

[1] Modulo de Adquisición National Instruments 6211 https://www.ni.com/pdf/manuals/375195d.pdf consultado 14/Abril/2020.
[2] A Low Power, Low Cost, Differential Input to a Single-Ended Output Amplifier https://www.analog.com/en/analog-dialogue/raqs/raq-issue-145.html consultado 14/Abril/2020.
[3] Active Low-Pass Filter Design. Texas Instruments http://www.ti.com/lit/an/sloa049b/sloa049b.pdf consultado 14/Abril/2020.
[4] Filter Pro de Texas Instruments
[5] LMx58-N Low-Power, Dual-Operational Amplifiers http://www.ti.com/lit/ds/symlink/lm358-n.pdf consultado 14/Abril/2020.
[6] TL07xx Low-Noise JFET-Input Operational Amplifiers http://www.ti.com/lit/ds/slos080n/slos080n.pdf consultado 14/Abril/2020.

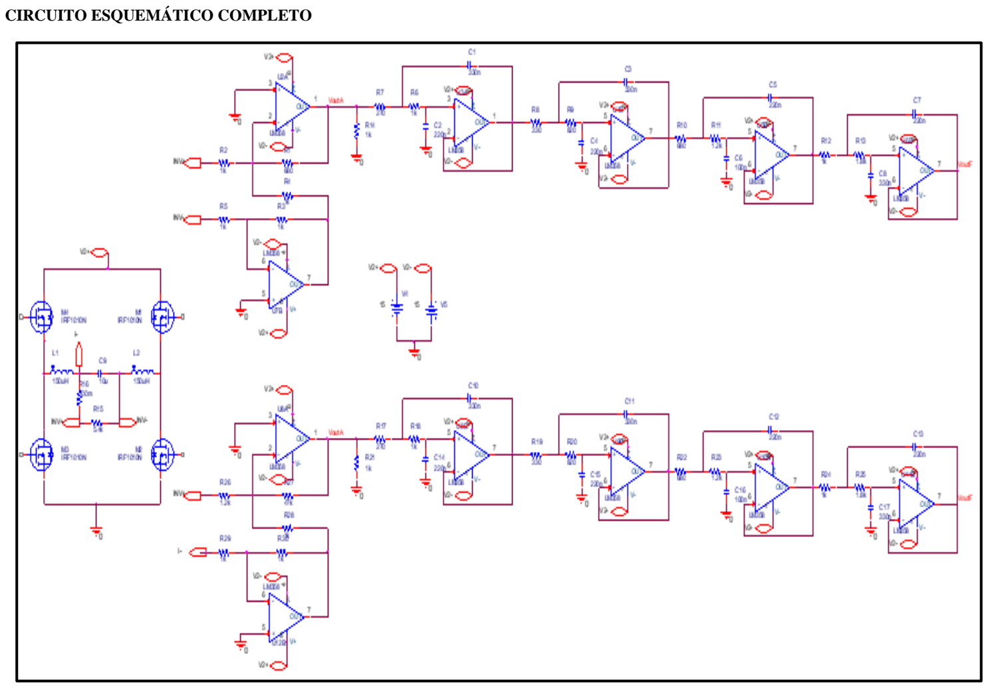
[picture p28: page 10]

CIRCUITO ESQUEMÁTICO COMPLETO

Anexo 1
Filtro Anti-aliasing obtenido en Filter Pro

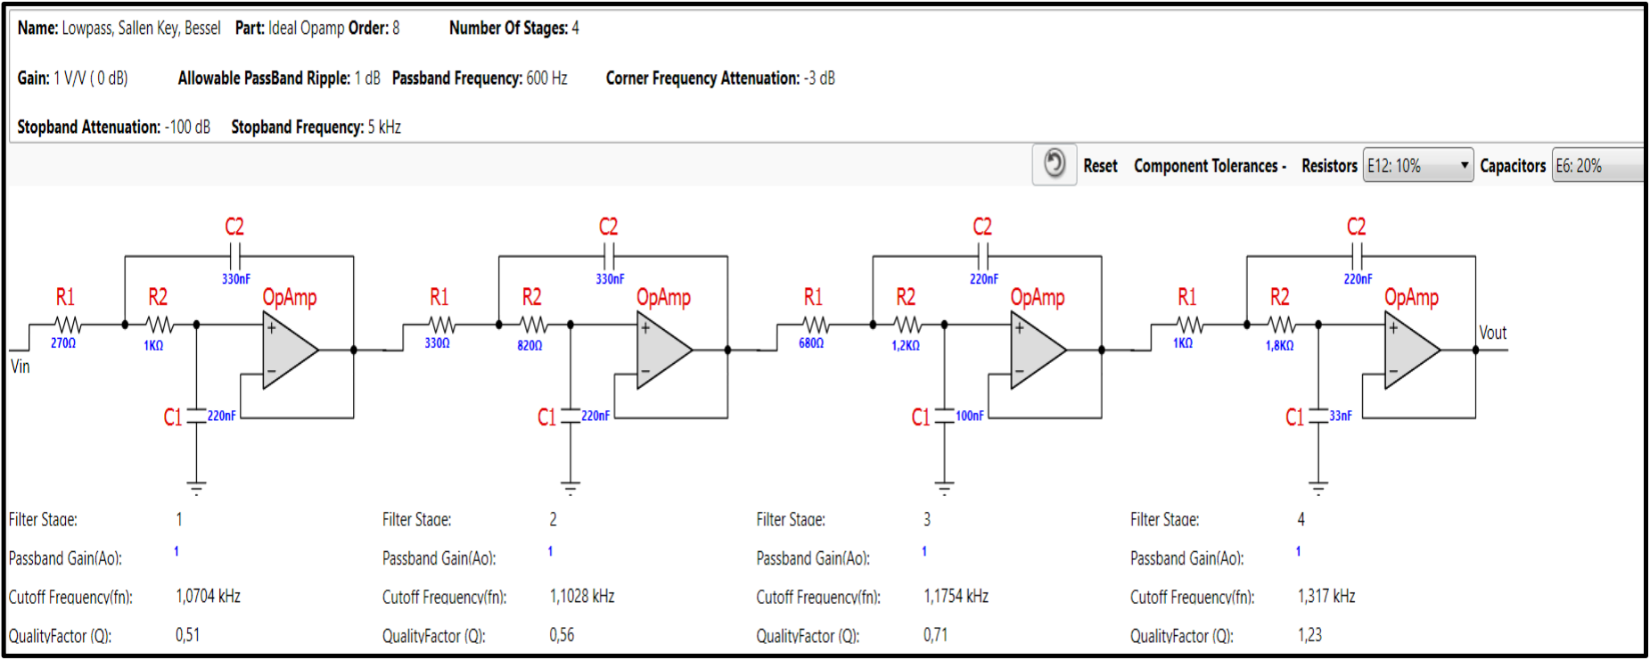
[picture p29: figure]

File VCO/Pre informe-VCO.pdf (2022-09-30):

DISEÑO DE CIRCUITOS NO LINEALES

PREINFORME ENTREGA 3: VCO

GRUPO 2

Daniel Esteban González Zuluaga

Juan Diego Sánchez Parra

Santiago Burgos Martínez

31/Marzo/2020

DEFINICIÓN DEL PROBLEMA

### 1. Descripción de la temática a tratar

Generador de onda VCO:
En esta práctica se presenta el desarrollo del bloque “Generador de onda seno” que conectara las etapas/diseños previamente realizados de PLL e Inversor puente H. Este generador de onda será un oscilador controlado por voltaje (VCO), el cual es un dispositivo que permite generar una onda seno a partir de una entrada de voltaje DC. Ahora, la frecuencia de oscilación será proporcional al voltaje que se le aplique a la entrada.

### 2. Alcance del diseño

Para esta práctica se consigue obtener una señal seno la cual cumpla con los parámetros que son requeridos en la etapa/diseño del Inversor. La señal seno será creada a partir del voltaje DC proveniente de la salida del filtro pasa bajas (salida de la etapa/diseño PLL).

### 3. Análisis de fenómenos físicos: mecánicos, eléctricos, etc., que permitan plantear la

solución en términos de ingeniería.

Un componente fundamental para la realización de esta práctica y muchos circuitos electrónicos es el capacitor, este permite mediante la carga y descarga ir modificando la forma de onda resultante. Para el circuito del VCO actuará en las etapas del primer integrador para cambiar una señal cuadrada en una señal triangular. Teniendo en cuenta el valor de este capacitor, esté se podrá cargar o descargar de forma rápida o lenta, lo cual es de gran importancia ya que dependiendo del valor de capacitancia este modificara que tan eficiente será la modificación de la señal cuadrada. En la siguiente imagen se observan las ecuaciones características de la carga y descarga del condensador en un circuito RC, donde hay que tener en cuenta que este comportamiento sucede tanto en corriente como en voltaje.

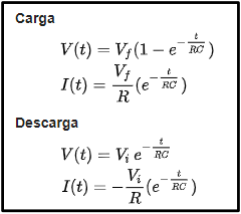
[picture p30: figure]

Figura 1. Carga y descarga de un condensador.
PROPUESTA DE SOLUCIÓN

### 1. Descripción general de la solución propuesta

Para poder desarrollar este proyecto se debe tener en cuenta los dos proyectos presentados anteriormente, el PLL y el inversor, en el numeral 8 “Consideraciones especiales o posibles problemas a tener en cuenta durante el montaje y pruebas” se encontrará la justificación del por qué es necesario tener presente estos proyectos. Ahora, el objetivo de este proyecto se centra en la creación e implementación de una onda seno

Ahora, la propuesta para este diseño está compuesta por dos grandes secciones. la primera es el circuito del VCO, el cual tiene un circuito integrador, un circuito comparador, y un circuito de acondicionamiento de señal cuadrada. La segunda sección está compuesta por un circuito recortador, un circuito integrador, y por último un circuito de acondicionamiento de señal seno.

### 2. Análisis y justificación de la solución

La solución planteada está compuesta por dos bloques principales y unos sub-bloques que en conjunto permiten un correcto funcionamiento del diseño.
El primer bloque de este proyecto es un VCO el cual se encarga de entregar una señal triangular con una frecuencia de 60Hz. para obtener esta señal triángulo el bloque del VCO hace uso de los circuitos comparador y acondicionador de onda cuadrada. El segundo bloque se encarga de tomar la señal triangular proveniente del primer bloque, en esta parte se realiza un recorte a la señal triángulo, posteriormente se integra para así obtener una señal seno y por último se acondiciona la señal seno para cumplir con los parámetros de diseño requeridos.

### 3. Descripción de posibles alternativas

Se plantearon 2 posibles alternativas:

- Aplicar el voltaje DC que se obtuvo en la salida del PLL como polarización en el circuito oscilador puente de Wien, el cual es un oscilador de ondas sinusoidales generadas mediante un amplificador operacional realimentado por un puente compuesto de cuatro resistencias y dos condensadores, como se muestra en la Figura 2. Se intentó probar esta idea en el simulador ORCAD, y funciona de forma correcta para un voltaje DC estable, pero al momento de cambiar los voltajes, teniendo en cuenta que la salida del PLL no es siempre constante y tiene un pequeño rango de variación, el oscilador deja de funcionar ya que esta señal no es el DC que se necesita para que el oscilador funcione correctamente. Para las pruebas de variación de voltaje se realizaron con una fuente cuadrada y un filtro pasa bajos, los cuales representan la salida del PLL.

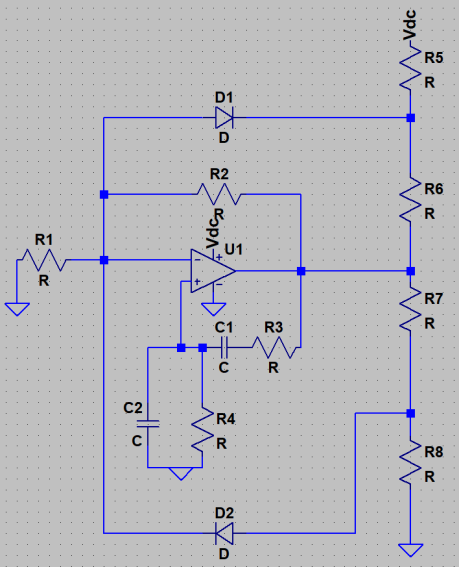
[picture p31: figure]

Figura 2. Circuito oscilador puente de Wien.[2]

- Se contempló la opción de unificar 3 circuitos: un VCO de onda cuadrada, seguido de un integrador y por último un conformador de onda. El modelo funcional de cada bloque se describe en la figura 4. Esta opción también plantea el uso de una sola fuente de polarización.

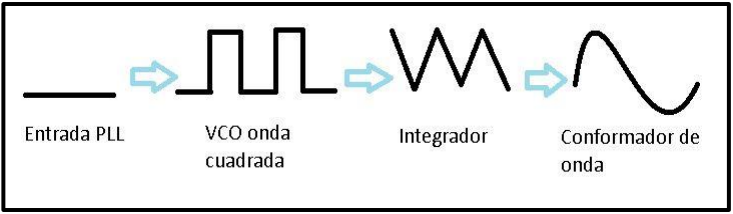
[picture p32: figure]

Figura 3. Funcionamiento opción 2.

Esta opción fue descartada ya que para su correcto funcionamiento se necesitan componentes de precisión, y el fin este proyecto es de no pedir componentes a Estado Unidos sino utilizar los que se encuentran en Bogotá. Además, para la implementación de un circuito integrador con una fuente única de polarización, se encontró una forma de hacer la cual eleva el nivel de dificultad de implementación de este (Circuito integrador Howland)[3].

### 4. Especificaciones generales a cumplir

El diseño del VCO debe cumplir con los siguientes requerimientos:

- Salida

### - Voltaje de salida V0 = 2. 8 Vpp

- Offset = 1.5 V

### - Frecuencia f = 60 Hz ± 5%

- Potencia de salida P 0 = 15 W
- Entrada
- Voltaje de entrada 8V

BLOQUES FUNCIONALES

### 1. Diagrama en bloques de la solución propuesta

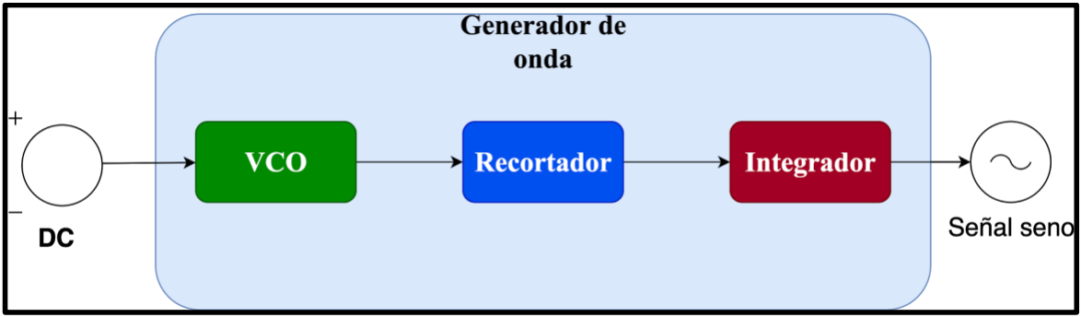
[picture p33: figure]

Figura 4. Diagrama en bloques del Generador de onda seno.

### 2. Justificación o análisis de cada uno de los bloques funcionales de la propuesta

VCO:
Este bloque tiene la función de recibir una señal DC proveniente del PLL (filtro pasa bajas), la frecuencia de salida de este bloque es controlada por medio de un capacitor y dos resistencias además del voltaje de entrada. En esencia, a partir de un DC obtener una señal triangular, la cual en los circuitos subsiguientes se adecuará para obtener una onda seno que servirá como referencia para el inversor.

Recortador:
Este bloque se encarga de tomar la onda triangular proveniente del bloque VCO, procesarla para obtener una señal triangular recortada por arriba y por abajo, es decir, una señal la cual presenta características de que está saturada por ambos extremos (superior e inferior) como se muestra en la Figura 5

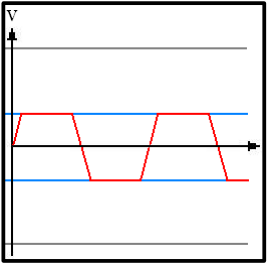
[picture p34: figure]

Figura 5. Salida bloque recortador.

Integrador:
Este bloque tiene la tarea de convertir la onda triangular recortada en una onda seno apta para ser utilizada como referencia en el diseño del inversor.

### 3. Especificaciones entrada-salida de cada bloque

VCO:
Entrada : Voltaje DC proveniente del PLL
Salida: Señal triangular de frecuencia dependiente del voltaje de entrada. Recortador:
Entrada: Señal triangular proveniente del VCO
Salida: Señal triángulo recortada por arriba y por abajo.
Integrador
Entrada: Señal de salida del recortador
Salida: Señal seno

### 4. Modelo funcional de cada bloque

Figura 6. Modelo funcional VCO.

Figura 7. Modelo funcional recortador.

Figura 8. Modelo funcional integrador.

### 5. Dimensionamiento de componentes (cálculos teóricos con comentarios

explicativos y criterios de selección de componentes)
A Continuación, se muestra un análisis de cada uno de los circuitos que componen el bloque del VCO:

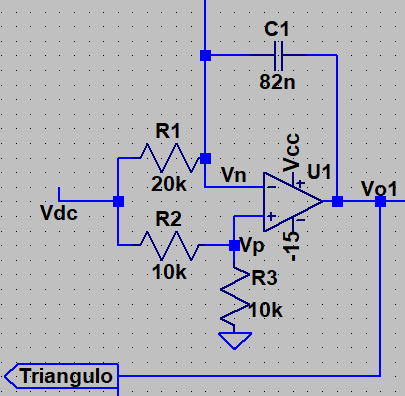
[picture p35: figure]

Figura 9. Esquemático primera parte VCO.

El circuito presente en la Figura 9, es el encargado de recibir el voltaje DC del PLL, y de entregar en su salida una señal triangular con la frecuencia de 60Hz.

VP1 =

Vdc ∗ R3
R2 + R3

Sabemos que R3 = R2, por lo tanto:
VP1 =

Vdc
2∗R2
Por ley de los operacionales el voltaje que se encuentra en el terminal no inversor se refleja en el terminal inversor.
VP1 = VN1


Figura 10. Esquemático segunda parte VCO.

### Vo2 = 15 si Vo1 < 15 V

### Vo2 = −15 si Vo1 > 15 V

El circuito presentado en la Figura 10 (circuito comparador), es el circuito que a partir de la señal triangular que viene del circuito previamente explicado, entrega en su salida Vcc o -Vcc, los cuales son la base para la señal cuadrada que se obtendrá en el siguiente circuito.


Figura 11. Esquemático tercera parte VCO.

Vo3 = Vo2 ∗ (

R8 + R7
R8

)

En el circuito de la Figura 11, se encarga de tomar la señal proveniente del circuito comparador y entrega en su salida una onda cuadrada.


Figura 12. Esquemático cuarta parte VCO.

Vo4 = Vo3

El circuito de la Figura 12, se encarga de tomar la señal cuadrada y cambiar/modificar su amplitud limitando por arriba y por abajo por D1 dando un Vo4 no mayor a +- 0.7V.


Figura 13. Esquemático completo VCO.

Ahora se muestra la ecuación de la salida del operacional para hallar qué proporción deben tener las resistencias R1y R4.

Vo1 = −

1
R1C

### ∫ (Vdc(t) − VN(t)) dt −

1
R4C

### ∫ (VC(t) − VN(t)) dt

Por la ley de los operacionales la primera integral es una constante

Vo1 = −

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
### ∫ (VC(t) − VN(t)) dt

La relación entre R1 y R4se observa que es de 2 a 1 respectivamente o viéndolo de otra forma R4 =
R1
2

A continuación, se presenta el análisis realizado a la segunda sección del circuito.


Figura 14. Esquemático circuito recortador.

En este circuito (recortador) la saturación de la señal triángulo está dada por los diodos, ya que el voltaje de salida máximo y mínimo está dado por:

Vo5

max = Vdc − Vd

Vo5

min = −Vdc + Vd


Figura 15. Esquemático buffer e integrador.

La función del buffer es evitar que entre el integrador y el recortada exista efecto de carga. En las secciones siguientes se presentan los cálculos realizados para la escogencia de los componentes de este circuito.

## f = 60ℎz

fc =

1

## 2ΠR12C

## fc < 10fs

R12 = 10R11

R11C = 0.016

Suponemos un capacitor de 1μFobteniendo así los siguientes valores de resistencia:

R11 = 16kΩ | R12 = 160kΩ


Figura 16. Esquemático circuito acondicionamiento final .

Por último, el circuito de acondicionamiento se encarga de tomar la señal seno proveniente del integrador, le añade un offset y modifica su amplitud para cumplir con los requisitos de diseño.

Voffset = (

Vcc ∗ R16
R16 + R18

) = 1.364 V

Vout = Vp (

R15 + R14
R15

)

Vout = Vp

(1.021)

Para mantener integridad y simetría de la señal en cada etapa del circuito se escogen resistencias iguales, en donde el circuito lo permita.


### 6. Simulación del sistema propuesto

Figura 17. Señal triangular a la salida del VCO.

Figura 18. Señal triangular recortada a la salida del recortador.

Figura 19. Señal seno a la salida del generador de onda.

Figura 20. FFT de la señal seno de salida del generador de onda.

7. Análisis de resultados de simulación, datos, gráficas, tablas, etc.

En las imágenes presentadas de la simulación podemos ver el funcionamiento esperado de cada etapa que hacen parte del Generador de onda seno VCO, en la primera imagen se ve la señal de salida de la etapa VCO que convierte un voltaje DC de entrada de 8V y una onda cuadrada a una señal triangular con voltaje pico a pico Vpp de 20 V y un Vrms igual a 5.77 V, con un periodo T de 16 ms y una frecuencia igual a 60 Hz, en esta etapa podemos ver que los requisitos de diseño se están cumpliendo.
En la segunda imagen ya podemos observar la señal de salida resultante de la etapa del integrador y del circuito de acondicionamiento, es decir, de todo el generador de onda, viendo una señal más curva que se asemeja a una señal seno con una frecuencia también de 60 Hz y un voltaje pico a pico Vpp de 2.8 V y un Vrms de 1 V que es el esperado según el diseño. Por último, se presenta la simulación FFT de la onda seno de salida.

### 8. Consideraciones especiales o posibles problemas a tener en cuenta durante el

montaje y pruebas

Para este diseño hay que tener en cuenta algunos parámetros del PLL y del Inversor PUENTE h. De esta forma, la salida del PLL es la entrada al Generador de onda y la salida de este va a ser la entrada de referencia para el circuito Inversor. Para que todo el proyecto en conjunto funcione correctamente hay que cumplir ciertas especificaciones, como lo es el voltaje de la señal de referencia que va a entrar al Inversor (mencionado en las especificaciones generales). Además, hay que tener presente que tipo de señal se encuentra en la salida del PLL para poder hacer los cálculos correctos en el Generador de onda seno VCO.

CIRCUITO ESQUEMÁTICO COMPLETO


Figura 221. Esquemático completo generador de onda seno.

BIBLIOGRAFÍA

[1] Teoría y circuitos vistos en las clases de: Dispositivos Electrónicos y Electrónica No lineal.
[2] Sedra/Smith “Circuitos microelectrónicos”, cuarta edición.
[3] AN-1515 A Comprehensive Study of the Howland Current Pump http://www.ti.com/lit/an/snoa474a/snoa474a.pdf consultado el 30/03/2020.
[4] “Condensador eléctrico” https://es.wikipedia.org/wiki/Condensador_el%C3%A9ctrico consultado el 30/03/2020.
[5] “Tecnología VCO” https://www.monografias.com/trabajos4/vco/vco.shtml consultado el 30/03/2020.
[6] “Amplificador integrador” https://wilaebaelectronica.blogspot.com/2017/01/amplificador-integrador.html (https://wilaebaelectronica.blogspot.com/2017/01/amplificador-integrador.html) consultado el 30/03/2020.

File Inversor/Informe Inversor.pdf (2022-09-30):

DISEÑO DE CIRCUITOS NO LINEALES

INFORME

GRUPO 2

Daniel Esteban González Zuluaga

Juan Diego Sánchez Parra

Santiago Burgos Martínez

24/Marzo/2020

CIRCUITO ESQUEMÁTICO COMPLETO DEFINITIVO

### 1. Circuito esquemático completo definitivo

El esquemático del circuito se encuentra en el ANEXO 1

### 2. Listado de componentes definitivo con número de parte

Componente | Cantidad | Número de parte | Esquemático
Controlador PWM | 1 | TL494 | U1
Driver | 2 | IR2110 | U2,U3
Mosfet | 4 | IRF1010N | Q1,Q2
Diodos | 6 | UF4007 1N4007 | DB1,DB2 D1,D2,D3,D4
Capacitores | 17 | 51pF 1nF 100nF 1uF 10uF 22uF | Cdt1, Cdt2 Ct Cp1, CU1, CU2, CU3, C1, C2 CB1-2, CB2-2 Cp2, CU1-2, CU2-2CU3-3 CB1, CB2
Inductancia | 1 | 300uf Fabricada | L1,L2
Capacitor AC | 1 | 10uf | C

Tabla 1. Listado de componentes.

PROTOCOLOS DE PRUEBAS EMPLEADOS

### 1. Variables medidas

- Voltaje de salida sin carga
- THD
- Frecuencia

### 2. Rango de estas medidas

- Voltaje de salida sin carga = 9 Vrms +- 2%
- THD <= 5%
- Frecuencia = 60 Hz

### 3. Equipos e instrumentos utilizados con sus referencias


Figura 1. Fuente de alimentación KEYSIGHT U8031A


Figura 2. Osciloscopio KEYSIGHT DSO-X2024A


Figura 3. Generador de funciones KEYSIGHT 33500B


Figura 4. Multímetro AGILENT 34401A

ANÁLISIS DE LOS RESULTADOS OBTENIDOS

### 1. Cuadro comparativo entre valores teóricos y/o simulados con respecto a los obtenidos

con el diseño.

Protocolo de pruebas

Mediciones | Experimental | Teórico
Vo | 5.3 Vrms | 9 Vrms
THD | √(ΣVrms) 2 √0. 2915 ∗ 100 = ∗ 100 Vf 5. 3 = 10. 18% | <=5%
Frecuencia | 61.2 Hz | 60Hz

Tabla 2. Protocolo de pruebas.

### 2. Evaluación de los resultados

Nota: Debido a la situación que se presenta en el país y las medidas tomadas para garantizar la seguridad de todos, no fue posible realizar a tiempo todas las medidas propuestas para el desarrollo del proyecto, medidas que mostrarían el desempeño completo del inversor.

Las mediciones realizadas y mostradas a continuación se hicieron con una onda seno usada como referencia para el integrado TL494 y la cual tiene los siguientes parámetros

### f = 60Hz

### A = 2.10 Vpp

### DC = 2.8 V −> offset

Las señales de control obtenidas de los drivers IR2110 para manejar el Gate de los Mosfet se evidencian en la Figura 5. Estas señales garantizan un correcto funcionamiento del puente H conformado por Mosfet ya que como característica diferenciadora entre estas dos señales es un tiempo muerto el cual evita que el circuito se encuentre funcionando en dos estados simultáneamente.


Figura 5. Salida HO y LO del controlador IR2110

La señal de salida del inversor se muestra a continuación, esta señal tiene un voltaje pico a pico de 15V o 5.3 Vrms.


Figura 6. Salida del inversor sin carga. Matlab

La distorsión armónica total o THD en la salida del inversor según los requerimientos debe ser menor o igual al 5%, sin embargo, en los cálculos realizados a la señal de salida obtenida de forma experimental se obtuvo un THD del 10%.

Ahora, el circuito del proyecto se implementó en una protoboard, donde el ruido y la distorsión aumentan por las conexiones internas (protoboard) y externas (cable UTP). Por lo tanto, se espera que en la entrega final y por consiguiente al entregar esta parte del proyecto en PCB mejore la distorsión armónica.

En la siguiente Figura se muestra los armónicos resultantes de la onda seno de salida.


Figura 7. THD de la señal de salida (seno). Matlab

De la figura 7 se observa que la señal obtenida en la salida del filtro LC del circuito tiene un rango dinámico de 51 dB entre la frecuencia fundamental y el armónico siguiente. Además, se comprueba que el armónico siguiente a la frecuencia fundamental se encuentra en la frecuencia de 120 Hz.

PROBLEMAS PRESENTADOS DURANTE EL DISEÑO

### 1. Descripción de los problemas encontrados durante el diseño

Manejo de la fuente y tierra flotante del controlador IR2110:
De la lectura del Datasheet del integrado IR2110 se tiene que los pines de VB y Vs
son los pines
de fuente y tierra que controlan los valores de HO, es decir, el funcionamiento del mosfet superior del puente H. Ahora al ser fuente y tierra flotante se necesita diseñar e implementar un circuito el cual permita obtener fuente y tierra VB y Vs que no sean flotante.


Figura 8. Diagrama interno del integrado IR2110.[6]

Diodo de la fuente Bootstrap:
Los diodos que se escogieron para la fuente Bootstrap fueron 1N4004. Al momento de tomar las medidas y de observar el comportamiento en la salida HO del controlador IR2110 se obtuvo una señal inestable y con ruido. cuando se esperaba una señal cuadrada estable y bien definidas como en la Figura 5.

Tiempo Muerto en señales de control (PWM): El controlador en sus entradas debe recibir dos señales como se muestran en la Figura 9.


Figura 9. Señales PWM con diferencia de tiempo muerto entre cada una.

El problema que se observó fue que se obtienen dos señales de la siguiente forma:


Figura 10. señales PWM sin diferencia de tiempo muerto entre cada una.

### 2. Descripción de soluciones implementadas

Bootstrap:
El desarrollo e implementación de la fuente Bootstrap se llevaron a cabo con la finalidad de controlar y manejar de forma adecuada los pines de fuente y tierra flotantes que tiene el integrado IR2110 los cuales se encargan de entregar la energía necesaria al Mosfet ubicado en la parte superior del puente H. La fuente Bootstrap se compone de un capacitor y un diodo como se muestra en Figura 11.


Figura 11. Esquemático de una fuente Bootstrap.[4]

Diodos ultra fast para la fuente Bootstrap:
Para resolver el problema presentado previamente con los diodos 1N4004 se decidió optar por diodos Ultra Rápidos o por sus siglas en inglés UF (Ultra Fast) los cuales permiten el cambio de carga en el capacitor más rápida y eficientemente como se evidencia en la Figura 5.

Filtro RC (pasa bajas) para añadir tiempo muerto:
Para obtener las señales de control como se muestran en la Figura 9, se opta por implementar un circuito RC (Figura 12) en las salidas de SPWM del integrado TL494. Posteriormente la salida del circuito RC ya se encuentra apta para ingresar al controlador IR2110.


Figura 12. Circuito RC para añadir tiempo muerto a la señal SPWM de control. LTSpice

### 3. Cambios realizados durante el diseño

Teniendo como referencia el esquemático entregado previamente (ANEXO 2). las modificaciones realizadas fueron: la adición de la fuente Bootstrap, el circuito RC para añadir tiempo muerto a las señales de control SPWM. Estos cambios permitieron el correcto funcionamiento del Proyecto.

### 4. Posibles alternativas para mejorar el diseño implementado

Para mejorar los resultados obtenidos la opción más viable es implementar el circuito en PCB. Para el caso de mejor el circuito implementado en Protoboard se propone mejorar los cables que realizan la interconexión de todos los componentes dentro del circuito. Además, se plantea el uso de cables de un calibre mayor para el correcto manejo de la corriente que entrega y consume el puente H.

CONCLUSIONES
- A pesar de no haber podido tomar todas las medidas correspondientes del inversor, las medidas que si se lograron realizar evidencian el desempeño en la salida de los drivers, la salida total, la distorsión THD que se logra y el cumplimiento del criterio de frecuencia.
- Se presentan diferencias entre el voltaje de salida especificado (9 Vrms) y el resultante (5.3 Vrms). Además, los inconvenientes presentados en el desarrollo del diseño fueron resueltos oportunamente, como lo fue la implementación de la fuente Bootstrap, el cambio de diodos por unos más rápidos y el circuito RC para añadir tiempo muerto a las señales SPWM.
- En el diseño total de este circuito se pudo evidenciar que, para tener un correcto funcionamiento, los componentes tienen que ser calculados y escogidos de la forma más exacta y precisa que se pueda. También, para la realización del filtro LC, el capacitor a escoger no pode ser cualquiera ya que tiene que cumplir con el requisito de manejar voltaje AC.
- Luego de realizar diversas pruebas y de observar el funcionamiento del puente H se evidenció el efecto de la corriente en la protoboard la cual presento partes plásticas derretidas. Este efecto producido en la protoboard es importante tenerlo en cuenta para el diseño del proyecto en PCB.
- los integrados y sus fabricantes son de vital importancia y de gran ayuda en el desarrollo del inversor ya que proporcionan información y detalles necesarios para la correcta implementación de cada uno, además de que ayudan a evitar un manejo inadecuado de los componentes como también un funcionamiento incorrecto del circuito.

BIBLIOGRAFÍA

[1] Datasheet Diodo UF4007 http://www.vishay.com/docs/88755/uf4001.pdf
[2] Ned Mohan, Tore M. Undelan, William P. Robbins “Electrónica de potencia-Convertidores, aplicaciones y diseño.” https://www.academia.edu/24345740/Electronica_de_potencia_mohan_3ra_edicion
[3] Nota de aplicacion “Using Monolithic High Voltage Gate Drivers” http://www.irf.com/technical-info/designtp/dt04-4.pdf
[4] Nota de aplicación “Bootstrap Network Analysis: Focusing on the Integrated Bootstrap Functionality” https://www.infineon.com/dgdl/an-1123.pdf?fileId=5546d462533600a40153559692661096 (https://www.infineon.com/dgdl/an-1123.pdf?fileId=5546d462533600a40153559692661096)
[5] Datasheet TL494 Pulse-Width-Modulation Control Circuits http://www.ti.com/lit/ds/symlink/tl494.pdf
[6] Datasheet Driver IR2110 https://www.infineon.com/dgdl/Infineon-IR2110-DataSheetv01_00-EN.pdf?fileId=5546d462533600a4015355c80333167e (https://www.infineon.com/dgdl/Infineon-IR2110-DataSheet-v01_00-EN.pdf?fileId=5546d462533600a4015355c80333167e)
[7] Datasheet Mosfet IRF1010n https://www.infineon.com/dgdl/irf1010npbf.pdf?fileId=5546d462533600a4015355da754e188 b (https://www.infineon.com/dgdl/irf1010npbf.pdf?fileId=5546d462533600a4015355da754e188b)

ANEXO 1- ESQUEMÁTICO COMPLETO FINAL


ANEXO 2- ESQUEMÁTICO PROPUESTO EN EL PRE-INFORME


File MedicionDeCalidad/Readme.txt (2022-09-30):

En esta carpeta se encuentran los calculos y componentes usados para la medicion de calidad del proyecto

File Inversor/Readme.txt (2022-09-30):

En esta carpeta se encuentran los calculos y componentes usados en el inversor

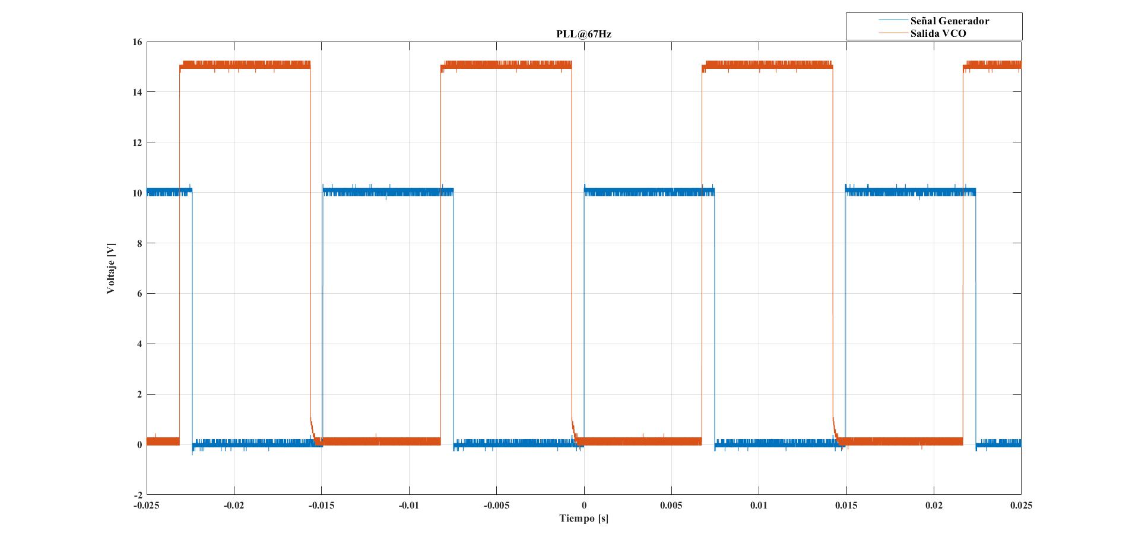
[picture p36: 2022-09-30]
PLL/Simulacion/PLL67.jpg

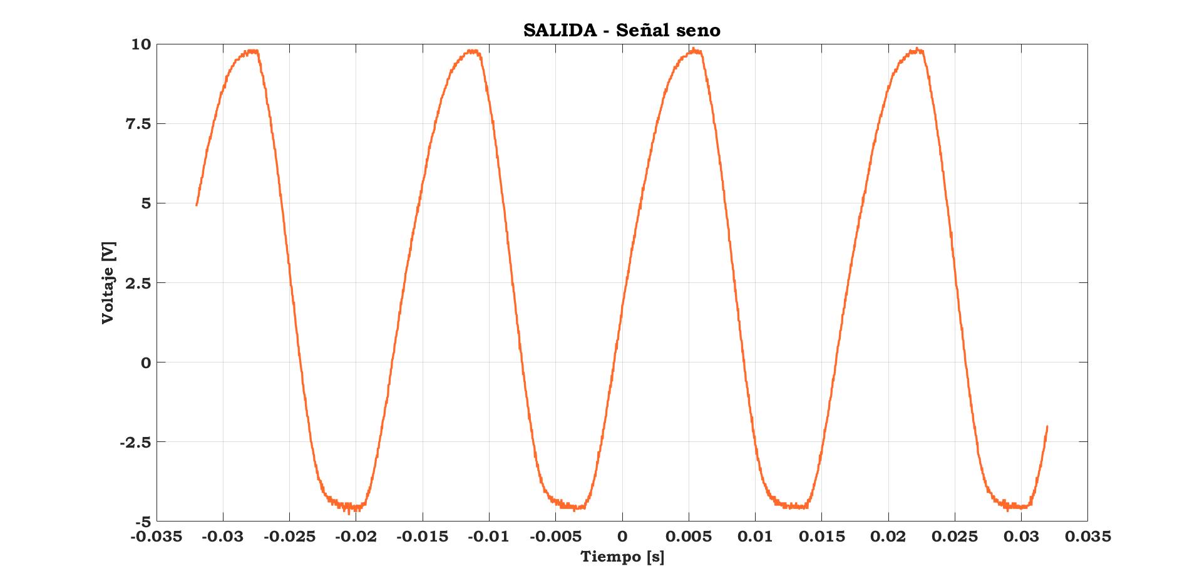
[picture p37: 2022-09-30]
Inversor/Simulacion/Señal salida.jpg

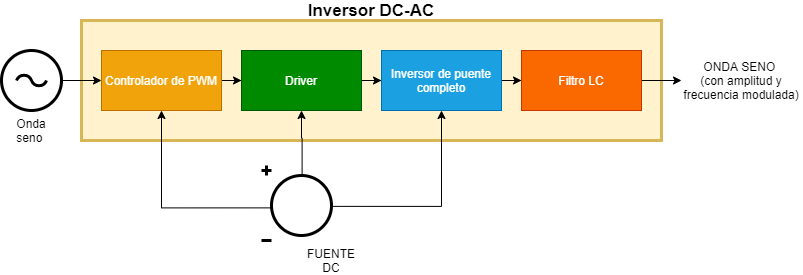
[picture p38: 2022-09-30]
Git_Images/DiagramaBloques_Inversor.png

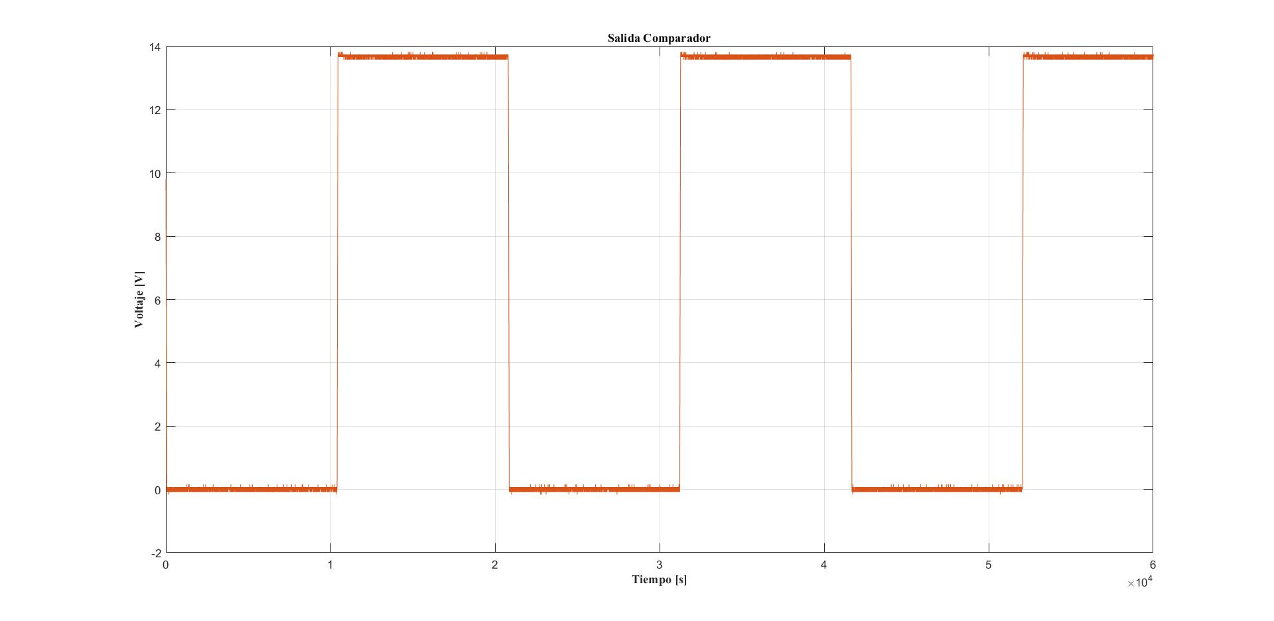
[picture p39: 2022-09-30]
PLL/Simulacion/comp.jpg
